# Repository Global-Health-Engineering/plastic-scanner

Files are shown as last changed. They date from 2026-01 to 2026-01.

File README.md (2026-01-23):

## Plastic Scanner
The goal of this project is to build a minimum viable product of the open-source [PlasticScanner](https://github.com/Plastic-Scanner) project and assess its suitability for the Global Health Engineering Lab. The design builds on the existing expertise of the project and incorporates the newest hardware version, Development Board 2.3. The overall objective of the project is to evaluate the scanner’s adaptability to the use case in Malawi and identify opportunities for improvement. This scanner is fully functional and can be reproduced for testing and development purposes. However, it is not recommended for any commercial application. Further development is still required.

<p align="center">
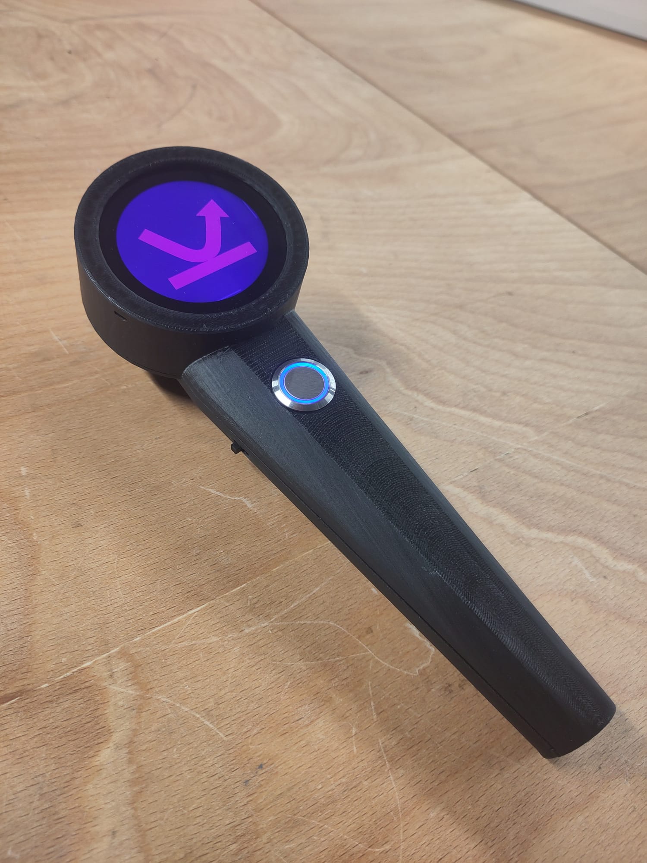
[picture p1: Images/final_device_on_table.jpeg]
  
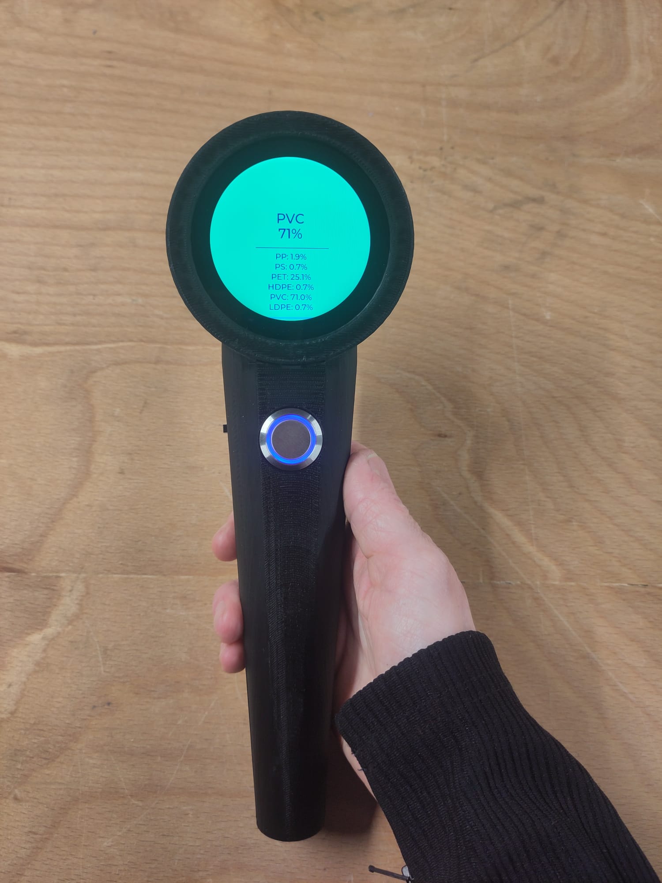
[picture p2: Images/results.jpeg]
  
</p>

## Introduction
Plastic is a widely used material, inexpensive to manufacture, and therefore a common choice for single-use products. However, due to its extensive use, global plastic pollution and its subsequent degradation in landfills into micro- and nanoplastics are threatening ecosystems (Walker & Fequet, 2023). Estimates indicate that plastic consumption will increase from 464 Mt/y in 2020 to over 700 Mt/y by 2050 (Dokl et al., 2024). Plastic recycling is established, but it first requires thorough separation of plastic components. Industrial plastic scanners employ various spectroscopic methods, with Near-Infrared (NIR) spectroscopy being the primary technology (Werner et al., 2023). Light is emitted, and the reflected relative light intensity from the material is measured to identify its composition.

Especially for small-scale recycling facilities and projects with limited financial resources, commercial plastic scanners are extremly expensive. Sorting is therefore done manually, which is often labor-intensive and inaccurate. An example is WASTE Adviser (WASTE Adviser Website, 2025), an NGO in Malawi that is establishing plastic beneficiation pathways for PET and HDPE. For the quality of the upcycled product, it is essential that the plastic is sorted with high accuracy. Otherwise, the recycled product suffers from embrittlement.

The PlasticScanner is an open source project which developed a low-cost plastic identification method. Utilizing inexpensive infrared LEDs and a machine learning model to identify the following six types of plastic:

plastic types

## How it works
The PlasticScanner allows the identification of six different plastic types using an approach called discrete near-infrared (NIR) spectroscopy. The IR LEDs on the Scanner module emit light one by one for a short period of time. Each time, the reflectance of the emitted light is measured by a photodiode.

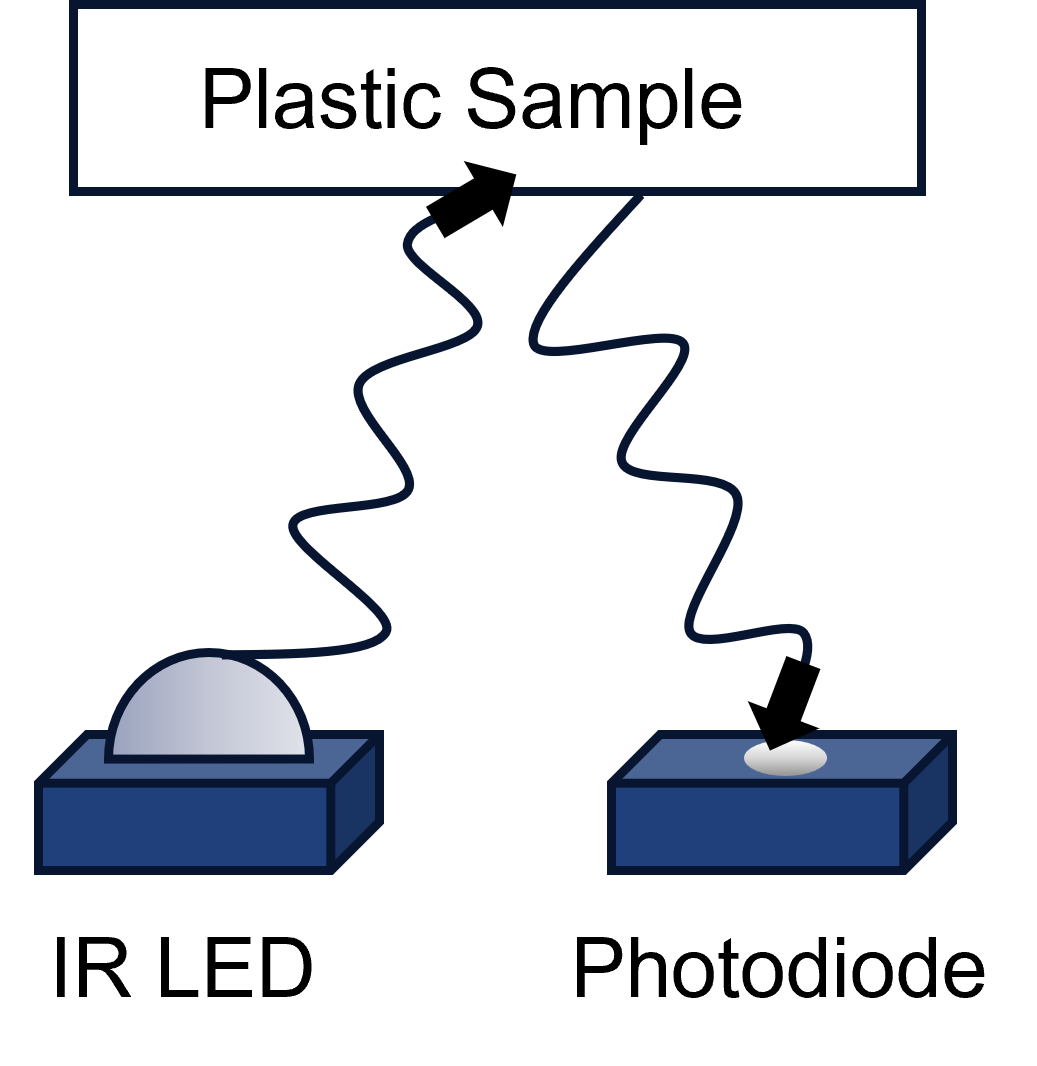
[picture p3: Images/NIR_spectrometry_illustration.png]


This results in a spectral analysis of the measured reflectance. Plastic identification is performed by comparing each measurement with the distinct reflectance spectra of the six plastic types (see illustration, for visualization only, not to scale). Since the device only provides eight readings at specific wavelengths and the actual reflectance spectra of plastics can be very similar, a machine learning model is applied. The model helps identify plastics more reliably without requiring a full spectral sweep. Additional information, such as color, can further improve the model, as dark plastics are particularly challenging to identify with this method.

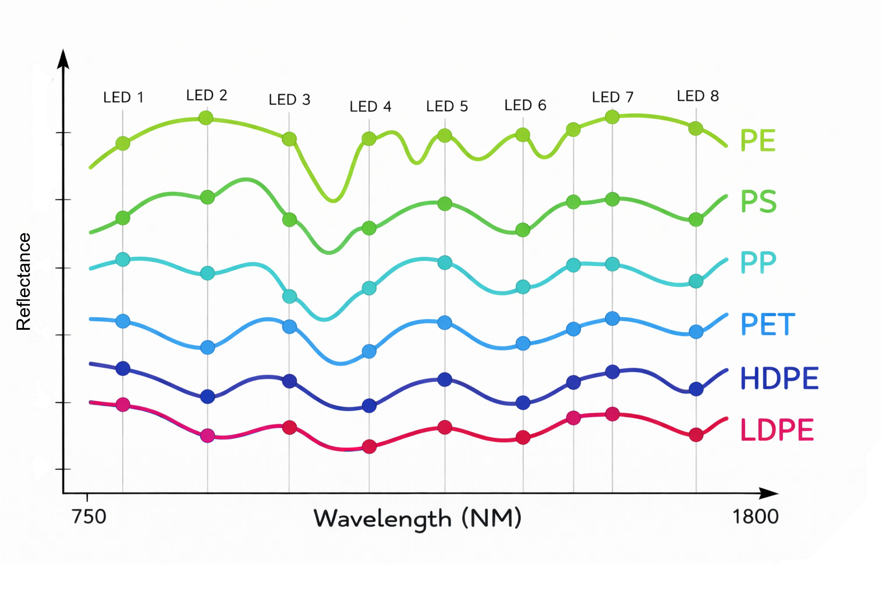
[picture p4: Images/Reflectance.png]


## Handheld Device
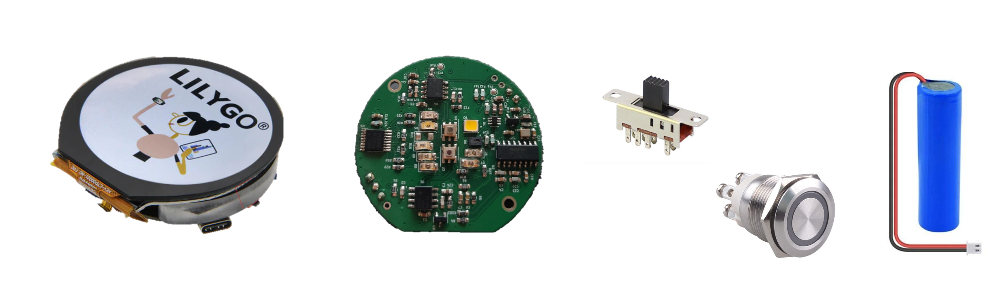
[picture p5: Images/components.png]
components


Components:
- 3D printed enclosure
- Scanning PCB (I²C for data transfer)
- Lilygo T-RGB UI interface, ESP32-S3 Microcontroller, USB-C port, Battery recharging, (I²C for data transfer)
- 3.7V 2600mAh Battery
- Button
- Power on/off shifter

## Future Work
- Create Training Data for machine learning Model with correct  IR LED range
- Retrain machine learning Model
- Add Color Sensor in Firmware
- Testing
- Supplychain addaptations (IR LED sourcing problems)

There is still a lot to improve! The most important point is that the current machine learning model still uses the old dataset, which relied on different IR LED ranges. To finalize this device, the model would need to be retrained with data for the wavelengths actually used (see Firmware). Due to this, testing has not yet been performed. Establishing the accuracy of the device and testing it for the intended use case is of high importance. The color sensor is included on the PCB but has not yet been implemented in the firmware. For future designs, the supplier of the IR LEDs should be changed, as especially high-wavelength LEDs are difficult to source and often have long delivery times. Switching to through-hole LEDs would increase the number of available suppliers and simplify sourcing.

## References
PlasticScanner Website: https://plasticscanner.com/ 

PlasticScanner Github: [Plastic-Scanner Project](https://github.com/Plastic-Scanner)

PCB: Lawrence R Kincheloe III, [handheld scanner](https://github.com/LokiMetaSmith/handheld-scanner.git)

CAD: Markus Glavind, [handheld scanner](https://github.com/Plastic-Scanner/handheld-scanner.git) 

Walker, T. R., & Fequet, L. (2023). Current trends of unsustainable plastic production and micro(nano)plastic pollution. TrAC Trends in Analytical Chemistry, 160, 116984. https://doi.org/10.1016/j.trac.2023.116984

Dokl, M., Copot, A., Krajnc, D., Fan, Y. V., Vujanović, A., Aviso, K. B., Tan, R. R., Kravanja, Z., & Čuček, L. (2024). Global projections of plastic use, end-of-life fate and potential changes in consumption, reduction, recycling and replacement with bioplastics to 2050. Sustainable Production and Consumption, 51, 498–518. https://doi.org/10.1016/j.spc.2024.09.025 

Werner, T., Taha, I., & Aschenbrenner, D. (2023). An overview of polymer identification techniques in recycling plants with focus on current and future challenges. Procedia CIRP, 120, 1381–1386. https://doi.org/10.1016/j.procir.2023.09.180

WASTE Adviser Website. (2025, Oktober 7). https://www.wasteadvisersmw.org/eu-building-better

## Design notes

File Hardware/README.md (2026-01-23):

## Hardware
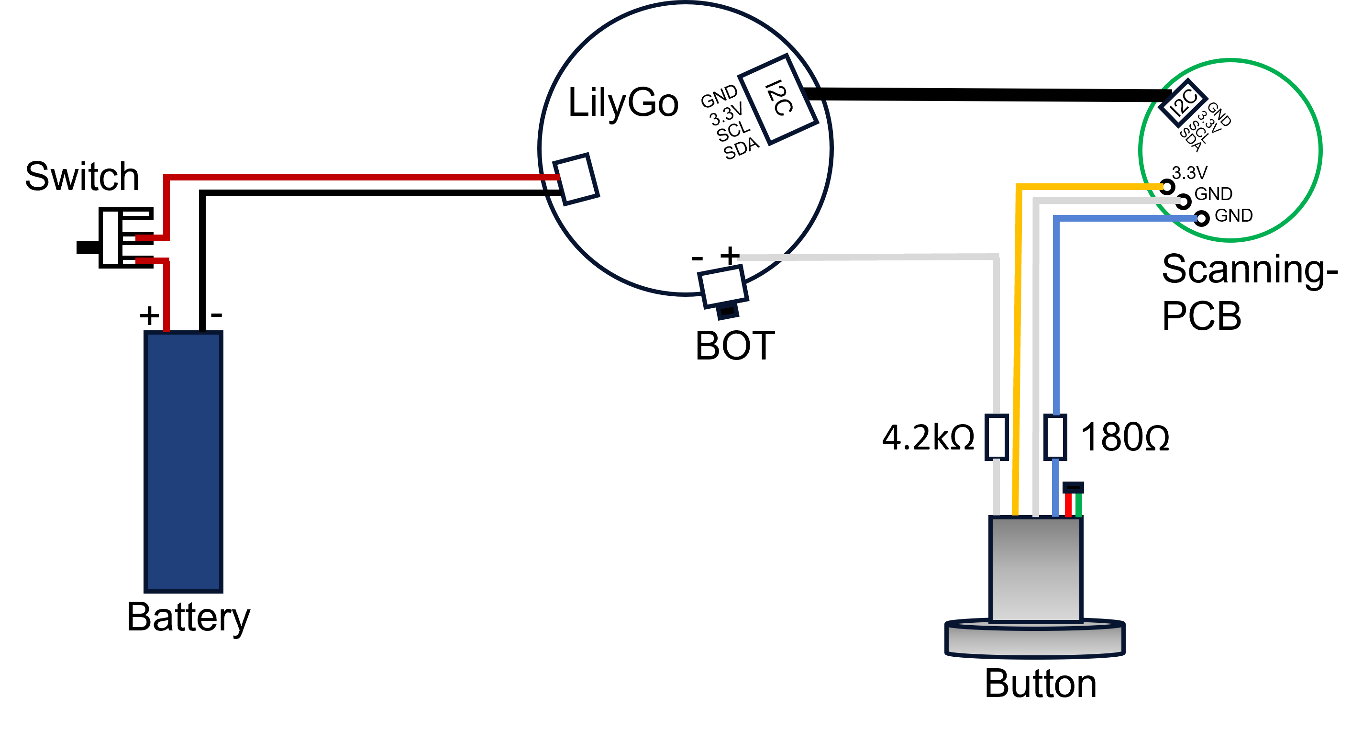
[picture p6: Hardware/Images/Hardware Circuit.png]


The hardware has the following components:

- Scanning PCB
- Lilygo T-RGB (ESP32-S3, Touch Screen, Battery recharging cycle, USB-C port, SD card)
- Button
- on/off Switch
- 3.7V 2600mAh Battery, rechargable 

Since the Lilygo board does not provide any dedicated external input pins, the onboard BOOT button was repurposed as an external input. Although the Scanning PCB includes additional external inputs, using them would require transmitting an extra button signal over the existing I²C link between the two boards, which would significantly increase implementation complexity.

## Scanning PCB
The scanning PCB was adapted from Lawrence Kincheloe's design, which represents the latest version of the handheld PlasticScanner. The IR LED wavelengths were modified to use available LEDs, and a few resistor values were adjusted accordingly.

Lawrence R Kincheloe III, [handheld scanner](https://github.com/LokiMetaSmith/handheld-scanner.git)

The PCB was soldered by hand using low-temperature solder paste, a soldering iron, a hot-air gun, and a microscope. The 1650nm IR LED is still missing, since its delivery data has been pushed to the 18.08.2026. 

<p align="center">
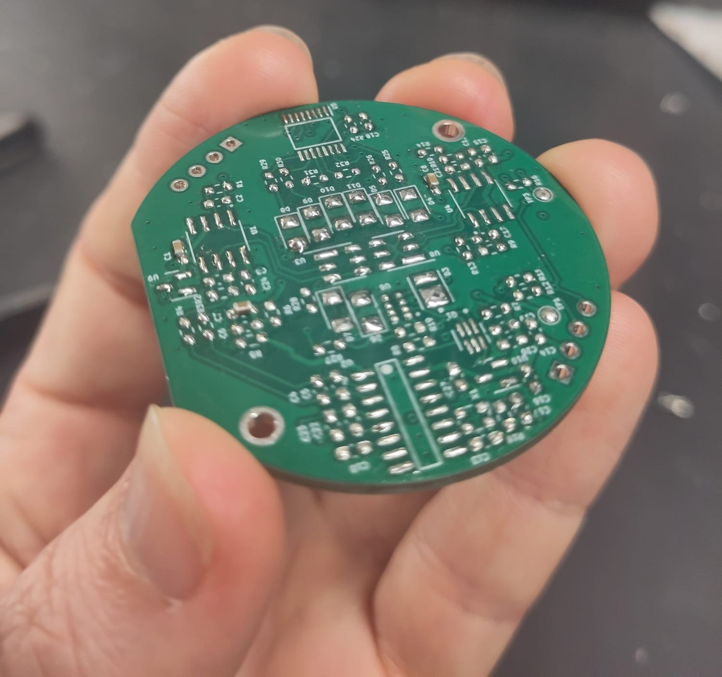
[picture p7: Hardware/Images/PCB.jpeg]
  
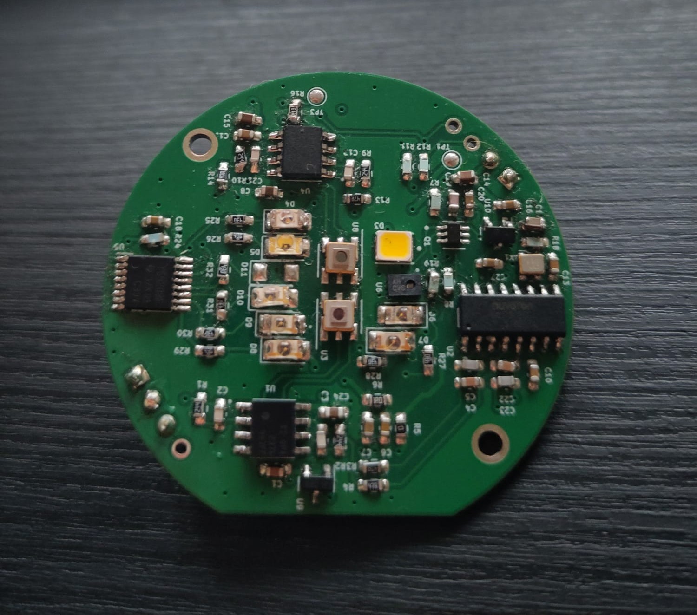
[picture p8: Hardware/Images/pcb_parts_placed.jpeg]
  
</p>

## Further Work
- IR LED sourcing problems -> change to push through LED's instead of SMD
- Separated LED PCB (first design exists)
- Find better solution for Button Signal (currently BOOT Button repurposed as an external input)
- to reduce cost the design could be changerd to only one photodiode or the LED count could be reduced

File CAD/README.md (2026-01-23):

## Design Enclosure 
The enclosure was designed to house the following components:
- Lilygo T-RGB board
- PCB scanner module
- Button
- 3.7V Battery (JST mini connector)
- On/Off switch
- 2x M3 screws (one 20mm, one 10mm)

The design includes a holding space for the battery and multiple fixtures for all other components. Since the project is still in the development phase, all fixtures were kept simple and reversible to ensure easy access to the components. Additionally, screw holders were added to provide the option of closing the device. These are intended for use with wooden screws and cannot be opened indefinitely, as the threads may break. However, the device closes firmly without screws, so for development purposes, they are not required.

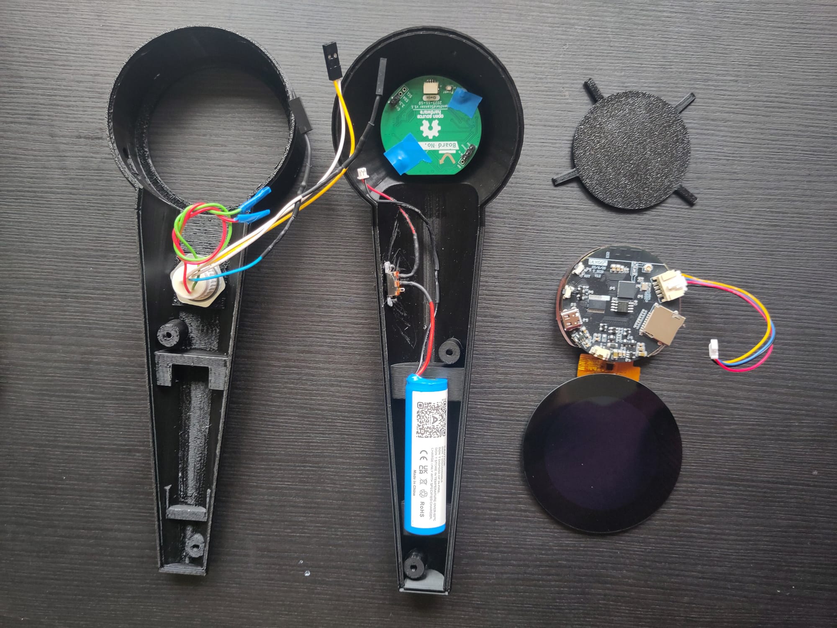
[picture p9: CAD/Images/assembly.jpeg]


## Printing Orientation:
A Bambu Studio printer was used with standard black PLA filament. The printing orientation was optimized for better surface texture. It was found to be best to orient the top part with the open side facing down, and the bottom part with the open side facing up. The open side is the side where the components are mounted. Printing at a slower speed with a layer height of 0.1 mm per slice produced the most uniform and pleasant-to-touch surface.

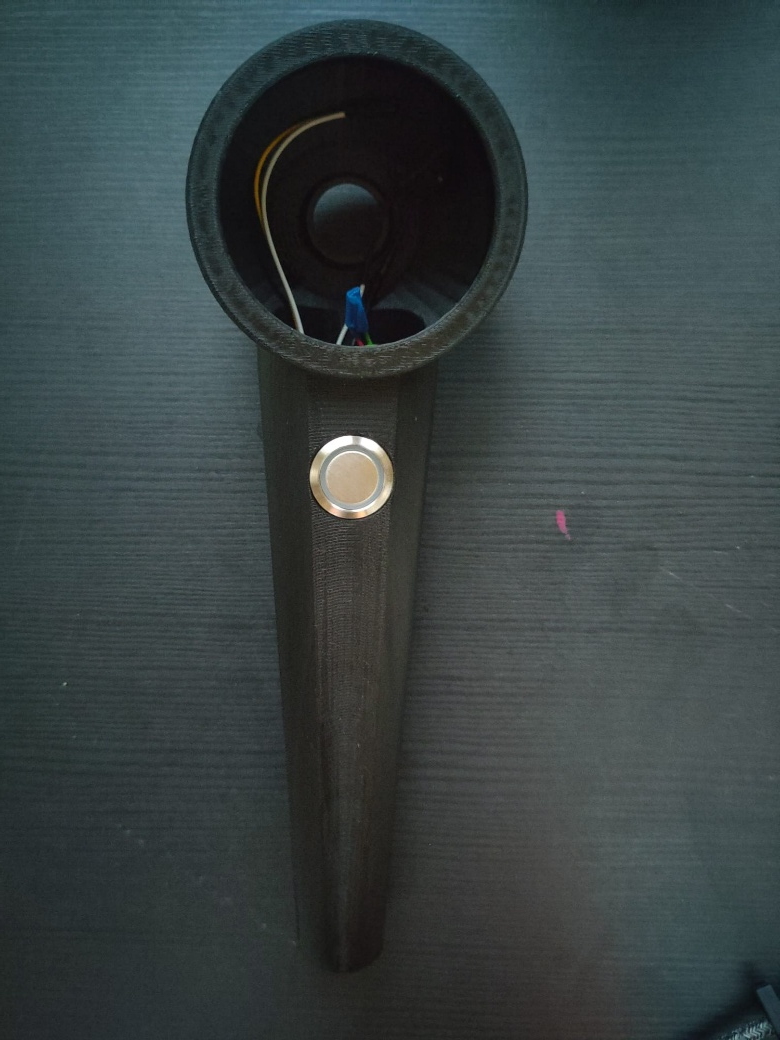
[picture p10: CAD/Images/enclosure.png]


## Further Work:
The USB-C port access could be improved and the fixtures changed to more durable solutions, for a final design. 

## References: 
The CAD was mainly influenced by the design analysis from Markus Glavind and Brandt Gregersen Gustav found here: 

Markus Glavind & Brandt Gregersen Gustav. (2023). PlasticScanner—Development and product realisation of a NIR polymer scanner. Master Thesis, DTU, 122.

Markus Glavind, [handheld scanner](https://github.com/Plastic-Scanner/handheld-scanner.git)

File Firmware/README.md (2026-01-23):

## Firmware
This is the firmware for the handheld PlasticScanner using a LilyGO board and is built as a PlatformIO project. The firmware can initiate a scan and send the received data to the machine learning model. The model then provides a prediction of which type of plastic was scanned. Since the current model was trained with different IR LEDs, the results are not accurate. The model would need to be retrained to generate correct predictions.

In the illustration, the 1720 nm LED is shown in red. It is currently unavailable and was replaced with a (green) 850 nm LED. The orange 1650 nm LED was initially available (delivery date pushed to 18.08.2026) but has now also been discontinued.

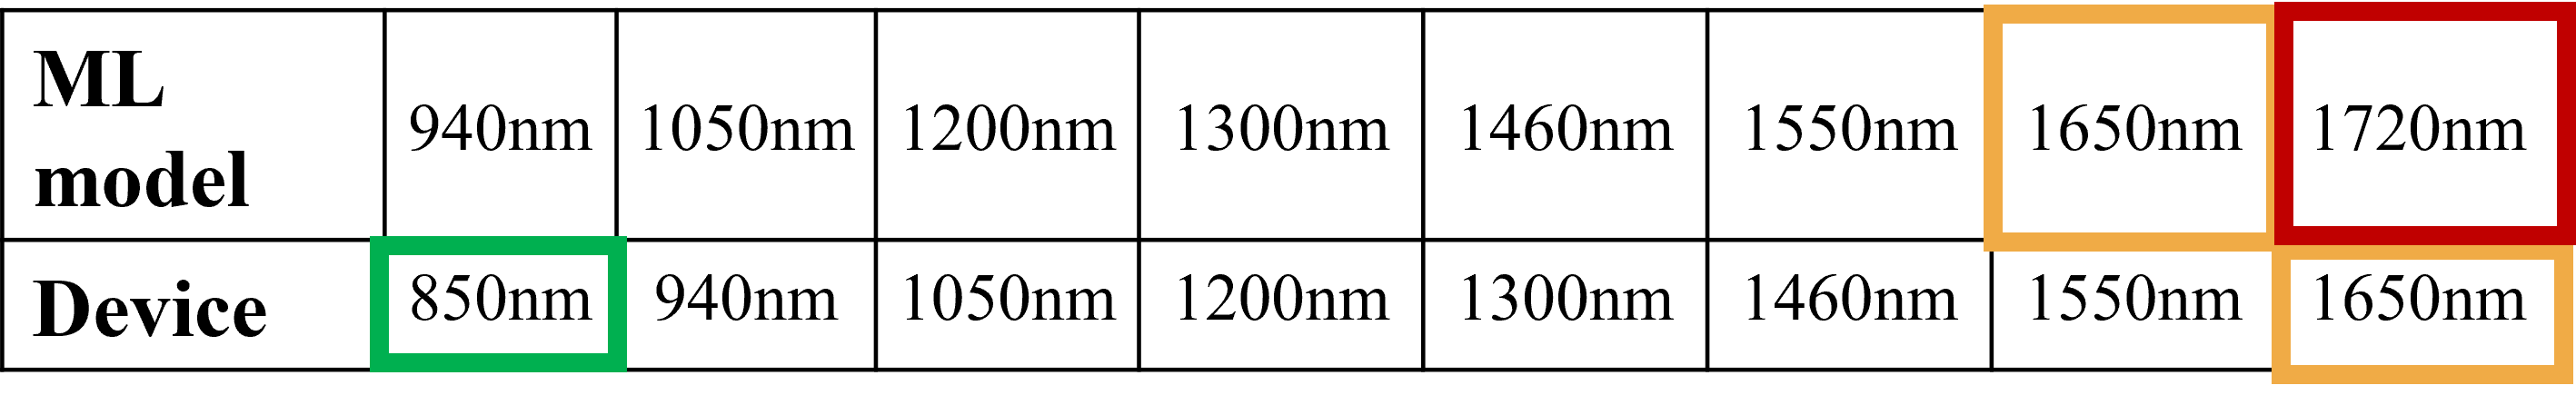
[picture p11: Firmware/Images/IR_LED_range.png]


Additionally, the firmware is still implemented as an example within the complete LilyGO firmware. This is necessary because the ESP32-S3 crashes immediately after startup if the firmware is used outside of the example structure. To run the current firmware, the platformio.ini file needs to be configured as follows:
 
<code style="color:red;">src_dir = examples/PlasticScanner</code>

Implemented features:
- Deep-sleep after long button press
- Deep-sleep after timeout of 5min
- Waking from Deep-sleep with long button press
- Scan after short button press
- old machine learning Model
- Startup UI
- Inital UI
- Scanning UI
- Results UI

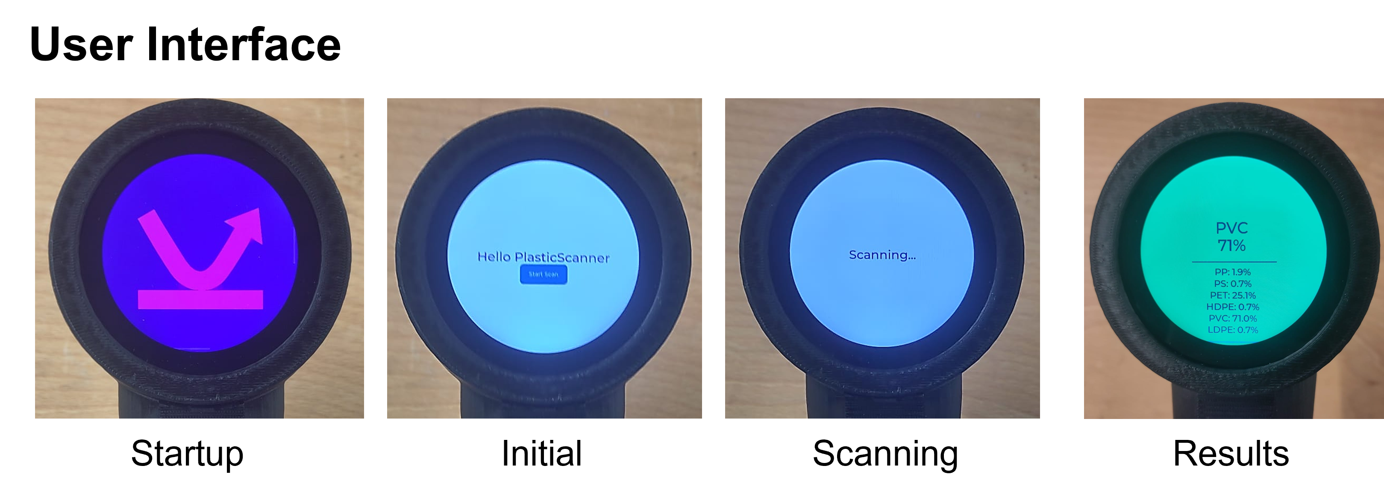
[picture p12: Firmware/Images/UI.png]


The firmware can be uploaded to the LilyGO by pressing the BOOT and RESET buttons simultaneously, then releasing RESET first, followed by BOOT, and immediately starting the firmware upload.

## Future Work
The next steps should be generating training data for the machine learning model, particularly for the 850 nm LED, and reviewing the available training data from the PlasticScanner project. Different versions of the model should be compared before retraining one of them with the specified IR LED wavelength range. Additionally, the AS7341 color sensor could be implemented in the firmware and incorporated into the training data.

## References
This firmware is based on the LilyGo T-RGB Firmware:
- https://github.com/Xinyuan-LilyGO/LilyGo-T-RGB.git

Machine Learning Repositories:
- https://github.com/Plastic-Scanner/Machine-Learning.git

Traning Data:
- https://github.com/Plastic-Scanner/Data.git 

Visualization, especially for Developement Board:
- https://github.com/Plastic-Scanner/PSplot.git

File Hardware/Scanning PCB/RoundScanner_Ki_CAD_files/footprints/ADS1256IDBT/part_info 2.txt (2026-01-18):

Manufacturer=Texas Instruments
PartNumber=ADS1256IDBT
PartCategory=Integrated Circuit
PackageCategory=Small Outline Packages
PinCount=28
Version=3.1
Released=2017-01-12 12:59:53
Downloaded=2022-05-06 10:48:30
3D=Y

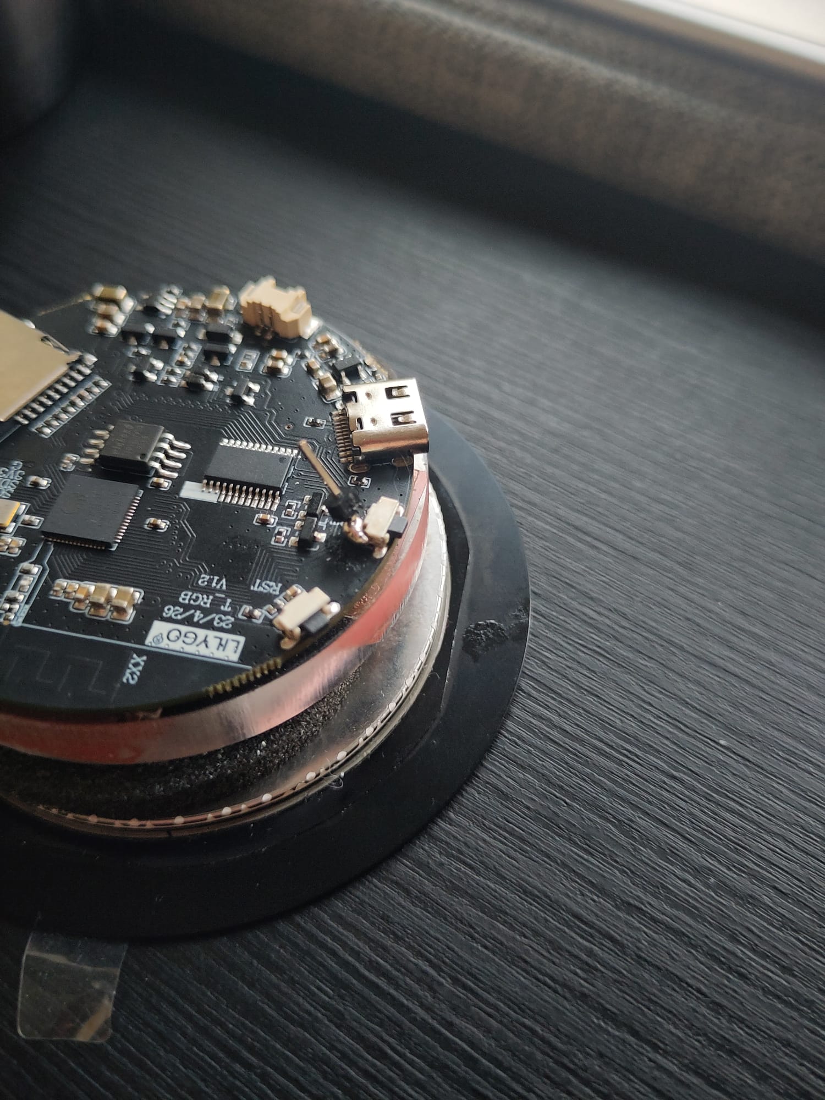
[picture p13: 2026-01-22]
Hardware/Images/highjacked_boot_pin.jpeg

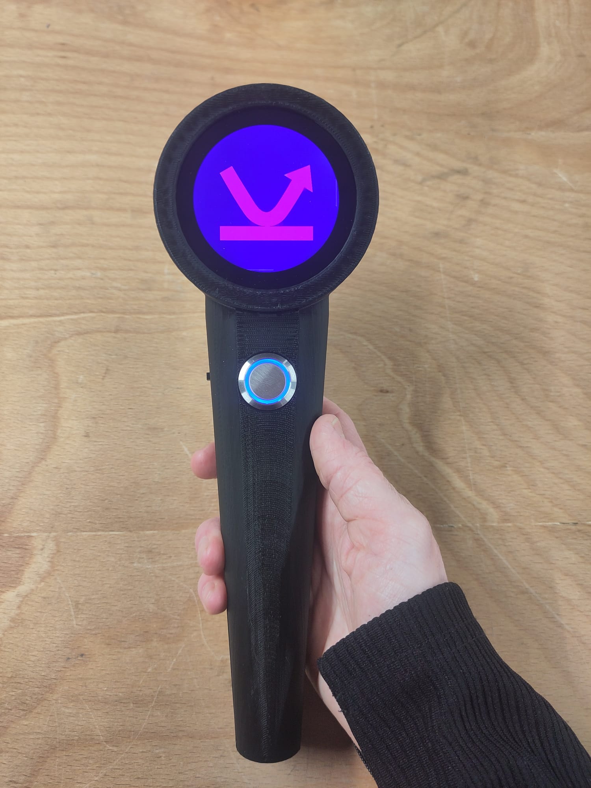
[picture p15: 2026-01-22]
Images/final_device.jpeg

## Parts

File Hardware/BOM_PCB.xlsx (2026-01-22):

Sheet: BOM Handheld
Part Number | sourced | placed | Designator | cathode/anode marking | Notes/Name | Footprint | Quantity | Manufacturer | Manufacturer Part Number (MPN) | Vendor / Supplier | Vendor P/N | Stock | Available | Unit Cost (USD) | Cost per device
1 | y | y | PCB Assembly |  | scanner board loki |  | 1 | JLCPCB |  |  |  | 5 | 4.00 | 1.36 | 1.36
2 | y | y | C1, C7, C10, C11, C13, C16, C20, C27 |  | 0.1uF 25V | C_0603_1608Metric_Pad1.08x0.95mm_HandSolder | 8 | KEMET | C0603C104K3RACTU | Digikey | 399-C0603C104K3RACTUDKR-ND | 16 | 8.00 | 0.08 | 0.64
3 | y | y | C2, C3, C12, C21 |  | 51pF 50V | C_0603_1608Metric_Pad1.08x0.95mm_HandSolder | 4 | KEMET | C0603X510K3HACTU | Digikey | 399-C0603X510K3HACTUDKR-ND | 8 | 4.00 | 0.1 | 0.4
4 | y | y | C14, C15, C19 |  | 10uF 10V | C_0603_1608Metric_Pad1.08x0.95mm_HandSolder | 3 | Murata Electronics | GRM188Z71A106KA73D | Digikey | 490-GRM188Z71A106KA73DDKR-ND | 6 | 3.00 | 0.28 | 0.84
5 | y | y | C4, C22 |  | 47nF 50V | C_0603_1608Metric_Pad1.08x0.95mm_HandSolder | 2 | KEMET | C0603X473J4RECAUTO | Digikey | 399-C0603X473J4RECAUTODKR-ND | 4 | 2.00 | 0.21 | 0.42
6 | y | y | C5, C23 |  | 100pF 50V | C_0603_1608Metric_Pad1.08x0.95mm_HandSolder | 2 | KEMET | C0603C101M3RACAUTO | Digikey | 399-C0603C101M3RACAUTODKR-ND | 4 | 2.00 | 0.24 | 0.48
7 | y | y | C6, C8, C24 |  | 1uF 25V | C_0603_1608Metric_Pad1.08x0.95mm_HandSolder | 1 | Taiyo Yuden | TMK107B7105KA-T | Digikey | 587-2984-6-ND | 4 | 3.00 | 0.08 | 0.08
8 | y | y | C17 |  | 22uF 25V | C_0603_1608Metric_Pad1.08x0.95mm_HandSolder | 1 | Murata Electronics | GRM188C61E226ME01W | Digikey | 490-GRM188C61E226ME01WDKR-ND | 4 | 3.00 | 0.41 | 0.41
9 | y | y | R7, R8, R11, R12, R19 |  | 10k | R_0603_1608Metric_Pad0.98x0.95mm_HandSolder | 5 | Vishay | MCT06030C1002FP500 | Digikey | MCT0603-10.0K-CFDKR-ND | 10 | 5.00 | 0.1 | 0.5
10 | y | y | R1, R2, R9, R10 |  | 240k | R_0603_1608Metric_Pad0.98x0.95mm_HandSolder | 4 | YAGEO | RT0603FRE07240KL | Digikey | 13-RT0603FRE07240KLDKR-ND | 8 | 4.00 | 0.1 | 0.4
11 | y | y | R3, R4, R13, R14 |  | 301 | R_0603_1608Metric_Pad0.98x0.95mm_HandSolder | 4 | YAGEO | RT0603FRE07301RL | Digikey | 13-RT0603FRE07301RLDKR-ND | 8 | 4.00 | 0.1 | 0.4
12 | y | y | R16, R26, R29, R30 |  | 150 | R_0603_1608Metric_Pad0.98x0.95mm_HandSolder | 4 | Vishay | MCT06030C1500FP500 | Digikey | MCT0603-150-CFDKR-ND | 8 | 4.00 | 0.1 | 0.4
13 | y | y | R18, R16 |  | 1k, R16 = 100 Ohm | R_0603_1608Metric_Pad0.98x0.95mm_HandSolder | 2 | Vishay | MCT06030C1001FP500 | Digikey | MCT0603-1.00K-CFDKR-ND | 4 | 2.00 | 0.1 | 0.2
14 | y | y | R27, R28 |  | 240 | R_0603_1608Metric_Pad0.98x0.95mm_HandSolder | 2 | Vishay | MCT06030C2400FP500 | Digikey | 749-1760-6-ND | 4 | 2.00 | 0.1 | 0.2
15 | y | y | R25 |  | 56 | R_0603_1608Metric_Pad0.98x0.95mm_HandSolder | 1 | YAGEO | RT0603FRE0756RL | Digikey | 13-RT0603FRE0756RLDKR-ND | 4 | 3.00 | 0.1 | 0.1
16 | y | y | R31 |  | 40 | R_0603_1608Metric_Pad0.98x0.95mm_HandSolder | 1 | Stackpole Electronics Inc | RMCF0603FT40R2 | Digikey | RMCF0603FT40R2DKR-ND | 4 | 3.00 | 0.1 | 0.1
17 | y | y | R32 |  | 130 | R_0603_1608Metric_Pad0.98x0.95mm_HandSolder | 1 | YAGEO | RT0603FRE07130RL | Digikey | 13-RT0603FRE07130RLDKR-ND | 4 | 3.00 | 0.1 | 0.1
18 | y | y | D2 |  | POWER LED RED | LED_0805_2012Metric_Pad1.15x1.40mm_HandSolder | 1 | Visual Communications Company - VCC | LSM0805412V | Digikey | 28-LSM0805412VDKR-ND | 3 | 2.00 | 0.43 | 0.43
19 | y | y | D3 | T | EAHC2835WD6 | Everlight-EAHC2835WD6-MFG | 1 | Everlight Electronics Co Ltd | EAHC2835WD6 | Digikey | 1080-1461-6-ND | 2 | 1.00 | 0.29 | 0.29
20 | y | y | D4 | T | 850bm DOM | LED_1206_3216Metric_Pad1.42x1.75mm_HandSolder | 1 | Würth Elektronik | 15412085A3060 | Digikey | 732-12009-6-ND | 2 | 1.00 | 0.57 | 0.57
21 | y | y | D5 | cathode dot | 940nm DOM | LED_1206_3216Metric_Pad1.42x1.75mm_HandSolder | 1 | SunLED | XZTNI55W-3 | Digikey | 1497-1368-6-ND | 2 | 1.00 | 0.48 | 0.48
22 | y | y | D6 | cathode dot | 1050nm DOM | LED_1206_3216Metric_Pad1.42x1.75mm_HandSolder | 1 | Marktech Optoelectronics | MTSM5010-843-IR | Digikey | 1125-1359-ND | 2 | 1.00 | 12.49 | 12.49
23 | y | y | D7 | anode dot | 1200nm DOM | LED_1206_3216Metric_Pad1.42x1.75mm_HandSolder | 1 | Marktech Optoelectronics | MTSM0012-844-IR | Digikey | 1125-MTSM0012-844-IRDKR-ND | 2 | 1.00 | 13.1 | 13.1
24 | y | y | D8 | anode dot | 1300nm DOM | LED_1206_3216Metric_Pad1.42x1.75mm_HandSolder | 1 | Marktech Optoelectronics | MTSM0013-844-IR | Digikey | 1125-MTSM0013-844-IRDKR-ND | 2 | 1.00 | 13.1 | 13.1
25 | y | y | D9 | anode dot | 1460nm DOM | LED_1206_3216Metric_Pad1.42x1.75mm_HandSolder | 1 | Marktech Optoelectronics | MTSM6014-844-IR | Digikey | 1125-MTSM6014-844-IRDKR-ND | 2 | 1.00 | 13.1 | 13.1
26 | y | y | D10 | anode dot | 1550nm DOM not available | LED_1206_3216Metric_Pad1.42x1.75mm_HandSolder | 1 | Marktech Optoelectronics | MTSM5015-194-IR | Digikey | 1125-MTSM5015-194-IRDKR-ND | 2 | 1.00 | 13.1 | 13.1
27 | y | y | D11 | cathode dot | 1650nm DOM not available | LED_1206_3216Metric_Pad1.42x1.75mm_HandSolder | 1 | Marktech Optoelectronics | MTSM5016-843-IR or MTSM5016-199-IR | Digikey | 1125-1362-ND | 0 | -1.00 | 23.9 | 0
28 | y | y | U1, U4 |  | OPA2376AID | SOIC127P599X175-8N | 2 | Texas Instruments | OPA2376AID | Digikey | 296-26263-5-ND | 3 | 1.00 | 3.15 | 6.3
29 | y | y | U2 |  | NAU7802SGI | Nuvoton-NAU7802SGI | 1 | Nuvoto Technology Corporation | NAU7802SGI | Digikey | NAU7802SGI-ND | 3 | 2.00 | 1.62 | 1.62
30 | y | y | U3 |  | MTSM2601SMF1-100 | SENSOR PHOTODIODE 800-2600NM SMD | 1 | Marktech Optoelectronics | MTSM2601SMF1-100 | Digikey | 1125-MTSM2601SMF1-100-ND | 1 | 0.00 | 36.62 | 36.62
31 | y | y | U5 |  | TLC59208FIPWR | SOP65P640X120-16N | 1 | Texas Instruments | TLC59208FIPWR | Digikey | 296-36508-6-ND | 3 | 2.00 | 1.97 | 1.97
32 | y | y | U6 |  | AS7341-DLGT color sensor | PSON80P310X200X110-8N | 1 | ams-OSRAM USA INC. | AS7341-DLGT | Digikey | AS7341-DLGTDKR-ND | 2 | 1.00 | 7.64 | 7.64
33 | y | y | U7 |  | AP7312-1833W6-7 | AP7312-1833W6-7 | 1 | Diodes Incorporated | AP7312-1833W6-7 | Digikey | AP7312-1833W6-7DIDKR-ND | 2 | 1.00 | 0.53 | 0.53
34 | y | y | U8 |  | MTSM1346SMF1-100 | SENSOR PHOTODIODE 1300NM 6SMD | 1 | Marktech Optoelectronics | MTSM1346SMF1-100 | Digikey | 1125-MTSM1346SMF1-100-ND | 1 | 0.00 | 33.55 | 33.55
35 | y | y | U9 |  | AP2120N-2.5TRG1 | IC REG LINEAR 2.5V 150MA SOT23 | 1 | Diodes Incorporated | AP2120N-2.5TRG1 | Digikey | AP2120N-2.5TRG1DICT-ND | 3 | 2.00 | 0.14 | 0.14
36 | y | y | U10 |  | AP2125N-1.8TRG1 | IC REG LINEAR 1.8V 300MA SOT23-3 | 1 | Diodes Incorporated | AP2125N-1.8TRG1 | Digikey | AP2125N-1.8TRG1DICT-ND | 3 | 2.00 | 0.17 | 0.17
37 | y | y | X1 |  | 4.9152 MHz | Oscillator_SMD_ECS_2520MV-xxx-xx-4Pin_2.5x2.0mm | 1 | ECS Inc. | ECS-2520MVLC-049-BN-TR | Digikey | 50-ECS-2520MVLC-049-BN-DKR-ND | 3 | 2.00 | 1.24 | 1.24
38 | y | y | Q1 |  | BSS138DW-7-F | Diodes_Inc._-_BSS138DW-7-F-A | 1 | Diodes Incorporated | BSS138DW-7-F | Digikey | BSS138DW-FDIDKR-ND | 2 | 1.00 | 0.45 | 0.45
39 | y | y | J1 |  | ThroughHole Pin socket | PinSocket_1x04_P2.54mm_Vertical | 1 |  |  |  |  | 5 | 4.00 | 0 | 0
40 | y | y | J3 |  | I2C JST socket | JST_SH_SM04B-SRSS-TB_1x04-1MP_P1.00mm_Horizontal | 1 | JST Sales America Inc. | SM04B-SRSS-TB | Digikey | 455-SM04B-SRSS-TBDKR-ND | 5 | 4.00 | 0.5 | 0.5
41 | y | y | J4 |  | ThroughHole Pin socket | PinSocket_1x04_P2.54mm_Vertical | 1 |  |  |  |  | 5 | 4.00 | 0 | 0
42 | y | y |  | Assembly component | Button |  | 1 | Lumex Opto/Components Inc. | WS48M-A12RGB12 | Digikey | 67-WS48M-A12RGB12-ND | 1 | 1.00 | 18.3 | 18.3 | Total PCB $ | 164.42
43 | y | y |  | Assembly component | On/off switch |  | 1 | C&K | OS102011MS2QN1 | Digikey | CKN9565-ND | 1 | 1.00 | 0.71 | 0.71 | Total PCB Fr | 131.39
44 | y | y |  | Assembly component | LilyGo-TRGB |  | 1 | LilyGo | Lilygo T-RGB ESP32-S3 2.1/2.8 round display | Lilygo |  | 1 | 1.00 | 30.04 | 30.04
45 | y | y |  | Assembly component | 3.7V Battery |  | 1 | Nvidia | AccuCell Akku Nvidia Shield P2570, Nvidia LC18650 | Digitec | 23192203 | 1 | 1.00 | 38.03 | 38.03
46 | y | y |  | Assembly component | I2C JST Cable, QWIIC CABLE GROVE ADAPTER 100MM |  | 1 | SparkFun Electronics | 15109 | Digikey | 1568-15109-ND | 1 | 1.00 | 1.95 | 1.95
 |  |  |  |  |  |  |  |  |  |  |  |  |  | Total $ | 253.45
 |  |  |  |  |  |  |  |  |  |  |  |  |  | Total Fr | 202.53

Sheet: BOM Developement board
Part Number | sourced | Designator | Part Name / Description | Notes | Manufacturer | Manufacturer Part Number (MPN) | Vendor / Supplier | Vendor P/N | Quantity per Assembly | Footprint | Procurement Type | Stock | Available | Material / Specification | Unit Cost (USD) | Total Cost (USD)
1 | y | board | Development board |  | JLCPCB |  |  |  | 1 | - | Buy | 5 | 4
2 | y | C1, C7, C10, C11, C14, C16 | Capacitor 0.1u 10V |  |  |  |  |  | 6 | C_0805_2012Metric_Pad1.18x1.45mm_HandSolder | Lab stock | 12 | 6 | 0.1u
3 | y | C2, C3 | Capacitor 51p 50V |  |  |  |  |  | 2 | C_0805_2012Metric_Pad1.18x1.45mm_HandSolder | Lab stock | 4 | 2 | 51p
4 | y | C5, C8 | Capacitor 100p 50V |  |  |  |  |  | 2 | C_0805_2012Metric_Pad1.18x1.45mm_HandSolder | Lab stock | 4 | 2 | 100p
5 | y | C6, C15 | Capacitor 22u 16V |  |  |  |  |  | 2 | C_0805_2012Metric_Pad1.18x1.45mm_HandSolder | Lab stock | 4 | 2 | 22u
6 | y | C4 | Capacitor 47n 50V |  |  |  |  |  | 1 | C_0805_2012Metric_Pad1.18x1.45mm_HandSolder | Lab stock | 4 | 3 | 47n
7 | y | C9 | Capacitor 330p 16V |  |  |  |  |  | 1 | C_0805_2012Metric_Pad1.18x1.45mm_HandSolder | Lab stock | 4 | 3 | 330p
8 | y | C13 | Capacitor 10u 16V |  |  |  |  |  | 1 | C_0805_2012Metric_Pad1.18x1.45mm_HandSolder | Lab stock | 4 | 3 | 10u
9 | y | R15, R16, R17, R18, R19, R20, R21, R22 | Resistor 47 |  |  |  |  |  | 8 | R_0805_2012Metric_Pad1.20x1.40mm_HandSolder | Lab stock | 16 | 8 | 47
10 | y | R7, R8, R11 | Resistor 100 | change dependent on what LED ordered R8 = 75, R11 = 12, R7 = 91 or 100 |  |  |  |  | 3 | R_0805_2012Metric_Pad1.20x1.40mm_HandSolder | Lab stock | 6 | 3 | 100
11 | y | R1, R2 | Resistor 240k |  |  |  |  |  | 2 | R_0805_2012Metric_Pad1.20x1.40mm_HandSolder | Lab stock | 4 | 2 | 240k
12 | y | R3,R4 | Resistor 300 |  |  |  |  |  | 2 | R_0805_2012Metric_Pad1.20x1.40mm_HandSolder | Lab stock | 4 | 2 | 300
13 | y | R5, R6 | Resistor 51 |  |  |  |  |  | 2 | R_0805_2012Metric_Pad1.20x1.40mm_HandSolder | Lab stock | 4 | 2 | 51
14 | y | R9, R10 | Resistor 10k |  |  |  |  |  | 2 | R_0805_2012Metric_Pad1.20x1.40mm_HandSolder | Lab stock | 4 | 2 | 10k
15 | y | R14 | Resistor 1k |  |  |  |  |  | 1 | R_0805_2012Metric_Pad1.20x1.40mm_HandSolder | Lab stock | 4 | 3 | 1k
16 | y | D3, D12 | LED Red 0805 2012 metric | soldering max 260°C | Visual Communications Company - VCC | LSM0805412V | Digikey | 28-LSM0805412VDKR-ND | 2 | LED_0805_2012Metric_Pad1.15x1.40mm_HandSolder | Buy | 4 | 2 | red
17 | y | D1 | Sensor for Photodiodes | soldering max 260°C | Advanced Photonix | 0090-3111-185 | Digikey | 209-0090-3111-185DKR-ND | 1 | D_1206_3216Metric_Pad1.42x1.75mm_HandSolder | Buy | 4 | 3 | 800nm-1700nm, 0.95 A/W @ 1300nm, 1.0 A/W @ 1500nm
18 | y | D2 | LED Blue 0805 2012 metric | soldering max 260°C | Visual Communications Company - VCC | LSM0805463V | Digikey | 28-LSM0805463VDKR-ND | 1 | LED_0805_2012Metric_Pad1.15x1.40mm_HandSolder | Buy | 3 | 2 | blue
19 | y | D4 | IR 850nm | soldering max 260°C | Würth Elektronik | 15412085A3060 | Digikey | 732-12009-6-ND | 1 | LED_1206_3216Metric_Pad1.42x1.75mm_HandSolder | Buy | 2 | 1 | 855nm
20 | y | D5 | IR 940nm DOM | soldering max 260°C | SunLED | XZTNI55W-3 | Digikey | 1497-1368-6-ND | 1 | LED_1206_3216Metric_Pad1.42x1.75mm_HandSolder | Buy | 2 | 1 | 940nm
21 | y | D6 | IR 1050nm DOM | soldering max 260°C | Marktech Optoelectronics | MTSM5010-843-IR | Digikey | 1125-1359-ND | 1 | LED_1206_3216Metric_Pad1.42x1.75mm_HandSolder | Buy | 2 | 1 | 1050nm
22 | y | D7 | IR 1200nm DOM | soldering max 260°C | Marktech Optoelectronics | MTSM0012-844-IR | Digikey | 1125-MTSM0012-844-IRDKR-ND | 1 | LED_1206_3216Metric_Pad1.42x1.75mm_HandSolder | Buy | 2 | 1 | 1200nm
23 | y | D8 | IR 1300nm DOM | soldering max 260°C | Marktech Optoelectronics | MTSM0013-844-IR | Digikey | 1125-MTSM0013-844-IRDKR-ND | 1 | LED_1206_3216Metric_Pad1.42x1.75mm_HandSolder | Buy | 2 | 1 | 1300nm
24 | y | D9 | IR 1460nm DOM | soldering max 260°C | Marktech Optoelectronics | MTSM6014-844-IR | Digikey | 1125-MTSM6014-844-IRDKR-ND | 1 | LED_1206_3216Metric_Pad1.42x1.75mm_HandSolder | Buy | 2 | 1 | 1460nm
25 | y | D10 | IR 1550nm | DOM not available | Marktech Optoelectronics | MTSM5015-844-IR or MTSM5015-194-IR | Digikey | 1125-MTSM5015-844-IRDKR-ND | 1 | LED_1206_3216Metric_Pad1.42x1.75mm_HandSolder | Buy | 2 | 1 | 1550nm
26 | y | D11 | IR 1650nm | DOM not available | Marktech Optoelectronics | MTSM5016-843-IR or MTSM5016-199-IR | Digikey | 1125-1362-ND | 1 | LED_1206_3216Metric_Pad1.42x1.75mm_HandSolder | Buy | 0 | -1 | 1650nm
28 | y | U1 | low-noise operational amplifiers | amplifier AC/DC | Texas Instruments | OPA2376AID | Digikey | 296-26263-5-ND | 1 | SOIC127P599X175-8N | Buy | 3 | 2 | Amplifier AC-DC | 3.15
29 | y | U2 | 24bit analog digital converter | soldering max 260°C | Nuvoto Technology Corporation | NAU7802SGI | Digikey | NAU7802SGI-ND | 1 | Nuvoton-NAU7802SGI-0-0-0 | Buy | 3 | 2 |  | 1.62
30 | y | U3 | PMIC Voltageregulator 3.3V | soldering max 260°C | UMW | AMS1117-3.3 | Digikey | 4518-AMS1117-3.3DKR-ND | 1 | SOT-223-3_TabPin2 | Buy | 3 | 2 |  | 0.27
31 | y | U4 | LED driver IC linear PWM | soldering max 260°C, 50MA | Texas Instruments | TLC59208FIPWR | Digikey | 296-36508-6-ND | 1 | Texas_Instruments-TLC59208FIPWR-Level_A | Buy | 3 | 2 | 50mA
32 | y | SW1 | MCU Reset, push button |  | C&K | D6R90 F2 LFS | Digikey | 401-1995-ND | 1 | SW_PUSH_6mm | Buy | 2 | 1
33 | y | SW2 | Trigger, push button |  | C&K | D6R90 F2 LFS | Digikey | 401-1995-ND | 1 | SW_PUSH_6mm | Buy | 2 | 1
34 | y | A1 | Arduino Uno R3 | lab | Arduino | Arduino_UNO_R3 |  |  | 1 |  | Lab stock | 1 | 0
35 | y | FB1 | FerriteBead |  |  |  | Digikey |  | 1 |  | Buy | 4 | 3
36 | y | J1, J4, J5 | Conn_01x04 | P2.54mm vertical Socket | Adam Tech | SMC-1-04-1-GT | Digikey | 2057-SMC-1-04-1-GT-ND | 3 |  | Lab stock | 5 | 2
37 | y | J2 | Conn_01x08 | P2.54mm vertical Header | Samtec Inc. | TS-108-T-A-1 | Digikey | TS-108-T-A-1-ND | 1 |  | Lab stock | 5 | 4
38 | y | J3 | Qwiic, Connector |  | JST Sales America Inc. | SM04B-SRSS-TB | Digikey | 455-SM04B-SRSS-TBDKR-ND | 1 | JST_SH_SM04B-SRSS-TB_1x04-1MP_P1.00mm_Horizontal | Buy | 4 | 3

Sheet: BOM Jewiss
ID | Name | Designator | Footprint | Quantity | Manufacturer Part | Manufacturer | Supplier | Supplier Part | Stock | Available | Price
1 | board jewiss |  |  | 1 |  |  |  |  | 5 | 4
2 | LP5951MFX-1.5/NOPB | U5 | SOT-23-5_L2.9-W1.6-P0.95-LS2.8-BR | 1 | LP5951MFX-1.5/NOPB | TI(德州仪器) | LCSC | C2877802 | 3 | 2 | 1.154
3 | 0.1u | C12,C3,C9,C11 | L0603 | 4 | CL05A105KA5NQNC | SAMSUNG | LCSC | C52923 | 0 | -4 | 0.004
4 | 51p | C1,C2 | L0603 | 2 | CL05A105KA5NQNC | SAMSUNG | LCSC | C52923 | 0 | -2 | 0.004
5 | 47n | C4 | L0603 | 1 | CL05A105KA5NQNC | SAMSUNG | LCSC | C52923 | 0 | -1 | 0.004
6 | 100p | C5,C8 | L0603 | 2 | CL05A105KA5NQNC | SAMSUNG | LCSC | C52923 | 0 | -2 | 0.004
7 | 330p | C6,C7 | L0603 | 2 | CL05A105KA5NQNC | SAMSUNG | LCSC | C52923 | 0 | -2 | 0.004
8 | 22u | C10 | L0603 | 1 | CL05A105KA5NQNC | SAMSUNG | LCSC | C52923 | 0 | -1 | 0.004
9 | 240K | R1,R2,J1,J2,J3 | L0603 | 5 | RCT0212KJLF | HKR | LCSC | C174266 | 0 | -5
10 | 300 | R3,R4 | L0603 | 2 | RCT0212KJLF | HKR | LCSC | C174266 | 0 | -2
11 | 51 | R5,R6 | L0603 | 2 | RCT0212KJLF | HKR | LCSC | C174266 | 0 | -2
12 | SD0050-3111-011 | D1 | TO-46-2_BD5.5-P1.27-L | 1 | 1N4007W | BLUE ROCKET | LCSC | C328592 | 2 | 1 | 0.005
13 | HDR-M-2.54_1x8 | J4 | HDR-M-2.54_1X8 | 1 |  |  | LCSC | C190820 | 0 | -1 | 0.049
14 | 970nm | LED1 | LED1206-RD | 1 | 19-217/R6C-AL1M2VY/3T | EVERLIGHT(台湾亿光) | LCSC | C72044 | 0 | -1 | 0.019
15 | 1050nm | LED2 | LED1206-RD | 1 | 19-217/R6C-AL1M2VY/3T | EVERLIGHT(台湾亿光) | LCSC | C72044 | 2 | 1 | 0.019
16 | 1200nm | LED3 | LED1206-RD | 1 | 19-217/R6C-AL1M2VY/3T | EVERLIGHT(台湾亿光) | LCSC | C72044 | 0 | -1 | 0.019
17 | 1300nm | LED4 | LED1206-RD | 1 | 19-217/R6C-AL1M2VY/3T | EVERLIGHT(台湾亿光) | LCSC | C72044 | 2 | 1 | 0.019
18 | 1450nm | LED5 | LED1206-RD | 1 | 19-217/R6C-AL1M2VY/3T | EVERLIGHT(台湾亿光) | LCSC | C72044 | 0 | -1 | 0.019
19 | 1500nm | LED6 | LED1206-RD | 1 | 19-217/R6C-AL1M2VY/3T | EVERLIGHT(台湾亿光) | LCSC | C72044 | 0 | -1 | 0.019
20 | 1650nm | LED7 | LED1206-RD | 1 | 19-217/R6C-AL1M2VY/3T | EVERLIGHT(台湾亿光) | LCSC | C72044 | 0 | -1 | 0.019
21 | 1720nm | LED8 | LED1206-RD | 1 | 19-217/R6C-AL1M2VY/3T | EVERLIGHT(台湾亿光) | LCSC | C72044 | 0 | -1 | 0.019
22 | LED-0603_R | LED9 | LED0603_RED | 1 | 19-217/R6C-AL1M2VY/3T | EVERLIGHT(台湾亿光) | LCSC | C72044 | 0 | -1 | 0.019
23 | 750 | R7 | R0603 | 1 |  |  |  |  | 2 | 1
24 | 4.7k | R8,R9 | R0603 | 2 |  |  |  |  | 2 | 0
25 | 70 | R10 | R0603 | 1 |  |  |  |  | 0 | -1
26 | NAU7802SGI | U2 | SOP-16_L9.9-W3.9-P1.27-LS6.0-BL | 1 | NAU7802SGI | NUVOTON(新唐) | LCSC | C2614351 | 3 | 2 | 2.455
27 | TLC59108IPWR | U3 | TSSOP-20_L6.5-W4.4-P0.65-LS6.4-BL | 1 | TLC59108IPWR | TI(德州仪器) | LCSC | C130031 | 0 | -1 | 1.605
28 | OPA2376AIDGKR | U1 | VSSOP-8_L3.0-W3.0-P0.65-LS4.9-BL | 1 | OPA2376AIDGKR | TI(德州仪器) | LCSC | C54292 | 0 | -1 | 2.388
example:
0 | Main Assembly | PROD-1000 | Smart Sensor Device |  |  |  |  | 1 | A |  | EA |  |  |  | Top-level assembly
1 | PCB Assembly | PCB-001 | Main Control Board |  |  |  |  | 1 | A | FR4 | EA | 15.00 | 15.00 | 21
2 | Electronic Component | IC-ATMEGA328 | Microcontroller | Microchip | ATMEGA328P-AU | Digi-Key | 556-ATMEGA328PAU-ND | 1 | C |  | EA | 2.50 | 2.50 | 14 | Critical component
2 | Electronic Component | RES-10K | Resistor 10KΩ 1% | Yageo | RC0603FR-0710KL | Mouser | 603-RC0603FR0710KL | 10 | C |  | EA | 0.01 | 0.10 | 7 | Common resistor
1 | Mechanical | ENC-PLSTC | Plastic Enclosure | ABC Plastics | ENC-1001 | Local Supplier |  | 1 | A | ABS | EA | 5.00 | 5.00 | 10 | Injection molded
1 | Fasteners | SCR-M3 | Screw M3x6 | BoltCo | SC-M3X6 | Bolt Depot | 12345 | 4 | A | Steel | EA | 0.05 | 0.20 | 3

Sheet: BOM loki original
Index | Quantity | Part Number | Manufacturer Part Number | Description | Customer Reference | Available | Backorder | Unit Price | Extended Price USD
1 | 20 | 311-1088-1-ND | CC0603KRX7R7BB104 | CAP CER 0.1UF 16V X7R 0603 |  | 20 | 0 | 0.042 | 0.84
2 | 20 | 1276-2310-1-ND | CL10C510JB8NNNC | CAP CER 51PF 50V C0G/NP0 0603 |  | 20 | 0 | 0.041 | 0.82
3 | 4 | 311-4019-1-ND | CC0603JRX7R9BB473 | CAP CER 0.047UF 50V X7R 0603 |  | 4 | 0 | 0.1 | 0.40
4 | 2 | 311-1446-1-ND | CC0603KRX7R7BB105 | CAP CER 1UF 16V X7R 0603 |  | 2 | 0 | 0.14 | 0.28
5 | 6 | 1276-1038-1-ND | CL10A106KQ8NNNC | CAP CER 10UF 6.3V X5R 0603 |  | 6 | 0 | 0.13 | 0.78
6 | 2 | 490-7611-1-ND | GRM188R60J226MEA0D | CAP CER 22UF 6.3V X5R 0603 |  | 2 | 0 | 0.22 | 0.44
7 | 2 | 160-1405-1-ND | LTST-C150KRKT | LED RED CLEAR 1206 SMD |  | 2 | 0 | 0.33 | 0.66
8 | 2 | 1080-1461-1-ND | EAHC2835WD6 | LED COOL WHITE 6500K 2SMD |  | 2 | 0 | 0.39 | 0.78
9 | 2 | 1516-1269-1-ND | QBLP650-IR3 | LED CHIP IR WLP 850NM 1206 SMD |  | 2 | 0 | 0.66 | 1.32
10 | 2 | 1080-1350-1-ND | IR11-21C/TR8 | EMITTER IR 940NM 65MA 1206 |  | 2 | 0 | 0.47 | 0.94
11 | 1 | 1125-1342-ND | MTSM5010-199-IR | SWIR EMITTER 1050NM 1206 SMD |  | 1 | 0 | 18.02 | 18.02
12 | 1 | 5242-OIS-1501300N-X-TCT-ND | OIS-150 1300N-X-T | SWIR EMITTER 1300NM 1206 SMD FLA |  | 1 | 0 | 7.09 | 7.09
13 | 1 | 1125-MTSM6014-194-IRCT-ND | MTSM6014-194-IR | SWIR EMITTER 1460NM 1206 SMD |  | 1 | 0 | 11.91 | 11.91
14 | 1 | 5242-OIS-1501550N-X-TCT-ND | OIS-150 1550N-X-T | SWIR EMITTER 1550NM 1206 SMD FLA |  | 1 | 0 | 7.09 | 7.09
15 | 1 | 1125-1354-ND | MTSM5016-199-IR | SWIR EMITTER 1650NM 1206 SMD |  | 1 | 0 | 20.36 | 20.36
16 | 1 | 1125-MTSM0012-194-IRCT-ND | MTSM0012-194-IR | SWIR EMITTER 1200NM 1206 SMD |  | 1 | 0 | 11.91 | 11.91
17 | 2 | BSS138DW-FDICT-ND | BSS138DW-7-F | MOSFET 2N-CH 50V 0.2A SOT363 |  | 2 | 0 | 0.46 | 0.92
18 | 20 | 311-240KHRCT-ND | RC0603FR-07240KL | RES 240K OHM 1% 1/10W 0603 |  | 20 | 0 | 0.019 | 0.38
19 | 20 | P301HCT-ND | ERJ-3EKF3010V | RES SMD 301 OHM 1% 1/10W 0603 |  | 20 | 0 | 0.03 | 0.60
20 | 2 | 4988-NRC12ZOTRFCT-ND | NRC12ZOTRF | RES SMT12060M2A |  | 2 | 0 | 0.11 | 0.22
21 | 20 | 311-10KGRCT-ND | RC0603JR-0710KL | RES 10K OHM 5% 1/10W 0603 |  | 20 | 0 | 0.015 | 0.30
22 | 20 | 311-1.00KHRCT-ND | RC0603FR-071KL | RES 1K OHM 1% 1/10W 0603 |  | 20 | 0 | 0.019 | 0.38
23 | 20 | P43.00BZCT-ND | ERJ-PA3J430V | RES SMD 43 OHM 5% 1/3W 0603 |  | 20 | 0 | 0.056 | 1.12
24 | 2 | NAU7802SGI-ND | NAU7802SGI | IC ADC 24BIT SIGMA-DELTA 16SOP |  | 2 | 0 | 1.73 | 3.46
25 | 1 | 1125-MTSM2601SMF1-100-ND | MTSM2601SMF1-100 | SENSOR PHOTODIODE 800-2600NM SMD |  | 1 | 0 | 32.12 | 32.12
26 | 2 | 296-36508-1-ND | TLC59208FIPWR | IC LED DRVR LIN PWM 50MA 16TSSOP |  | 2 | 0 | 1.87 | 3.74
27 | 1 | AS7341-DLGTCT-ND | AS7341-DLGT | SENSOR OPT AMBIENT 8OLGA |  | 1 | 0 | 9.36 | 9.36
28 | 1 | 1125-MTSM1346SMF1-100-ND | MTSM1346SMF1-100 | SENSOR PHOTODIODE 1300NM 6SMD |  | 1 | 0 | 29.03 | 29.03
29 | 2 | AP2120N-2.5TRG1DICT-ND | AP2120N-2.5TRG1 | IC REG LINEAR 2.5V 150MA SOT23 |  | 2 | 0 | 0.38 | 0.76
30 | 2 | 50-ECS-2520MVLC-049-BN-CT-ND | ECS-2520MVLC-049-BN-TR | XTAL OSC XO 4.9152MHZ CMOS SMD |  | 2 | 0 | 1.16 | 2.32
31 | 2 | AP2125N-1.8TRG1DICT-ND | AP2125N-1.8TRG1 | IC REG LINEAR 1.8V 300MA SOT23-3 |  | 2 | 0 | 0.37 | 0.74
32 | 10 | 1276-1008-1-ND | CL10C101JB8NNNC | CAP CER 100PF 50V C0G/NP0 0603 |  | 10 | 0 | 0.026 | 0.26
33 | 4 | 296-22564-1-ND | OPA2376AIDR | IC OPAMP GP 2 CIRCUIT 8SOIC |  | 4 | 0 | 2.74 | 10.96
34 | 4 | 455-SM04B-SRSS-TBCT-ND | SM04B-SRSS-TB | CONN HEADER SMD R/A 4POS 1MM |  | 4 | 0 | 0.6 | 2.40

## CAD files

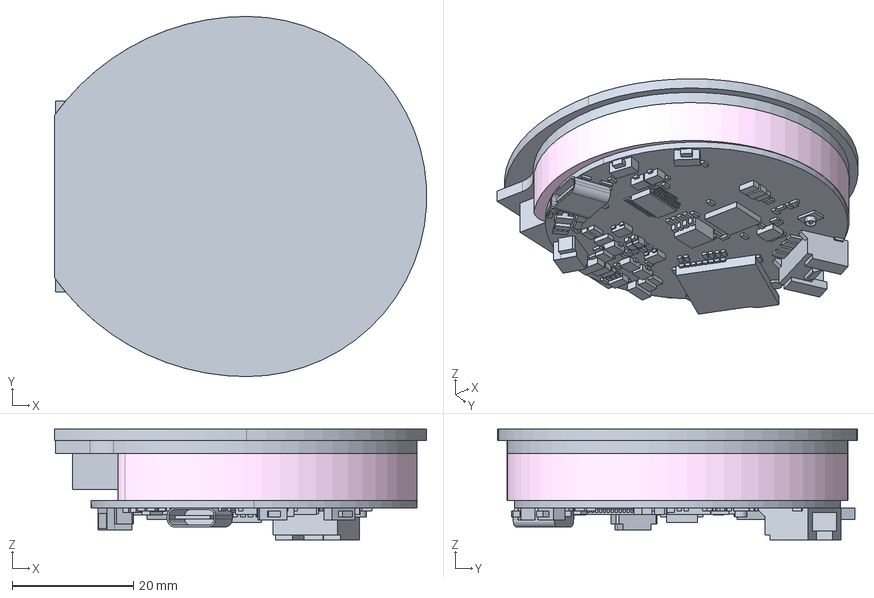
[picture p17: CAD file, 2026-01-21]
Firmware/Firmware Handheld Plastic Scanner LilyGo/dimensions/T-RGB-FULL-3D-2.1-Inches.stp
61.5 x 59.5 x 18.3 mm
LCD_BH021
T_RGB-V1_0
T_RGB_COVA

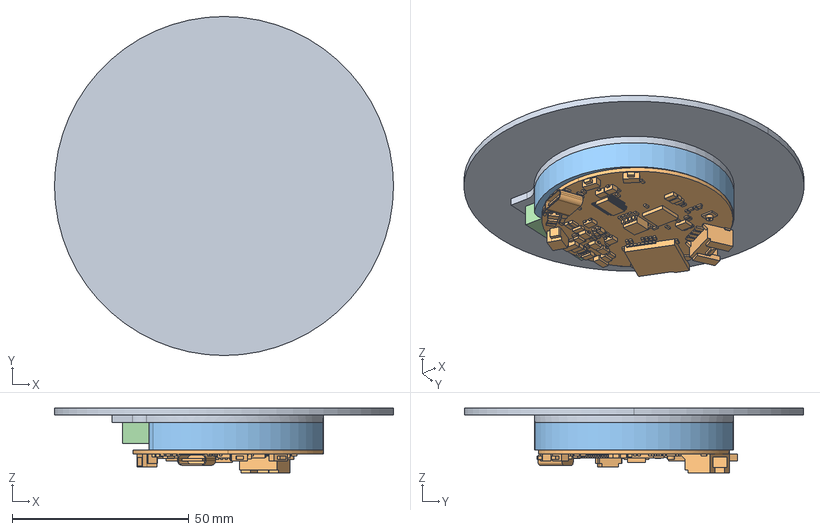
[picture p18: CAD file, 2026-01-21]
Firmware/Firmware Handheld Plastic Scanner LilyGo/dimensions/T-RGB-FULL-3D-2.8-Inches.stp
95.9 x 95.9 x 18.3 mm
LCD_BH021_2
T_RGB-V1_0_18
T_RGB_COVA_7

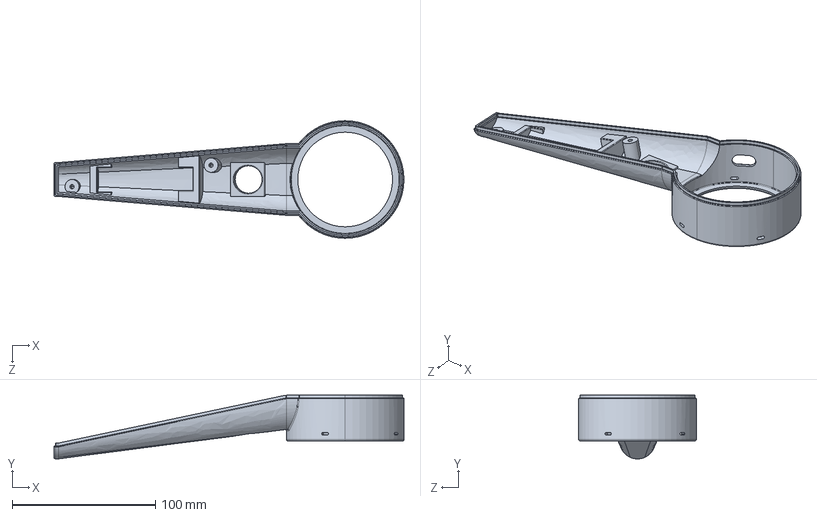
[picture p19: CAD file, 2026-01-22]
CAD/STEP files/top_shell_angle.STEP
244.0 x 44.5 x 82.0 mm

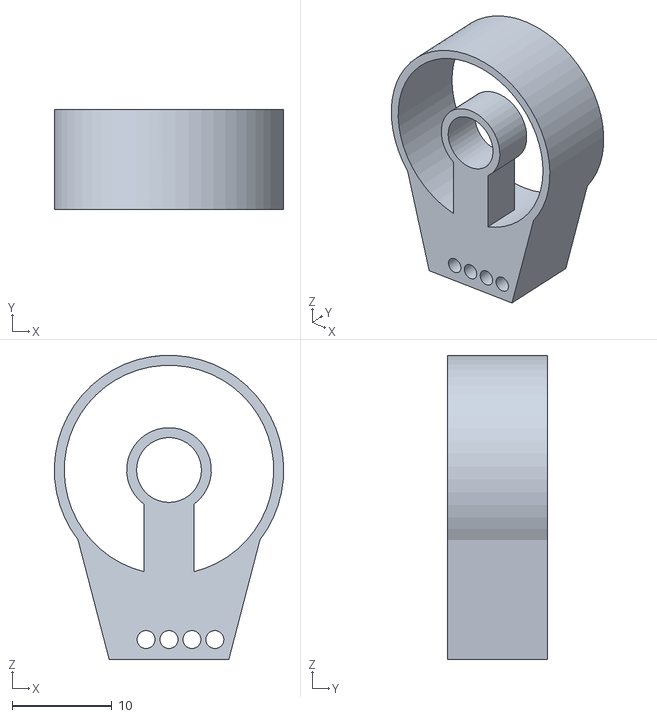
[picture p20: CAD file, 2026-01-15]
CAD/STL files/developmentboard_shield_LEDs.STL
23.0 x 10.0 x 30.5

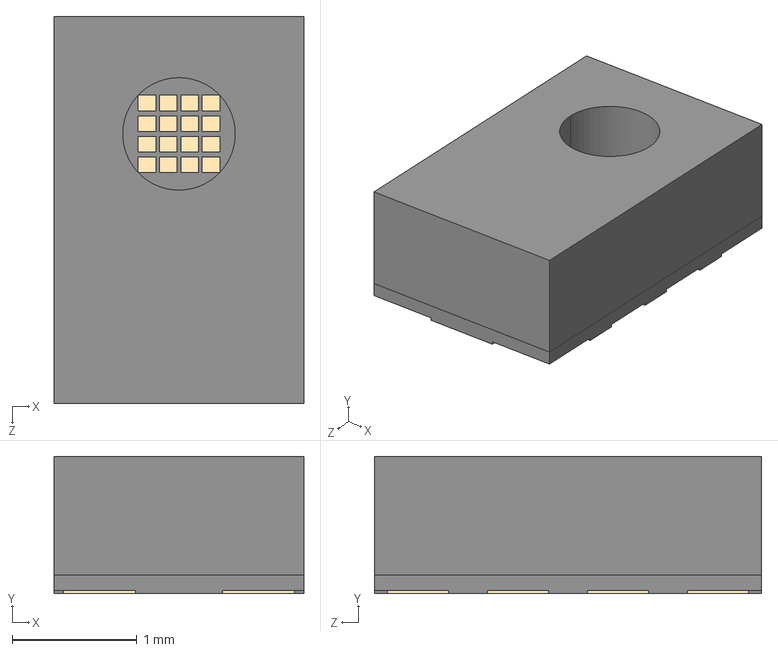
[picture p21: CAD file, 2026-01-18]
Hardware/Scanning PCB/RoundScanner_Ki_CAD_files/3dmodels/AS7341-DLGT.step
2.00 x 1.10 x 3.10 mm

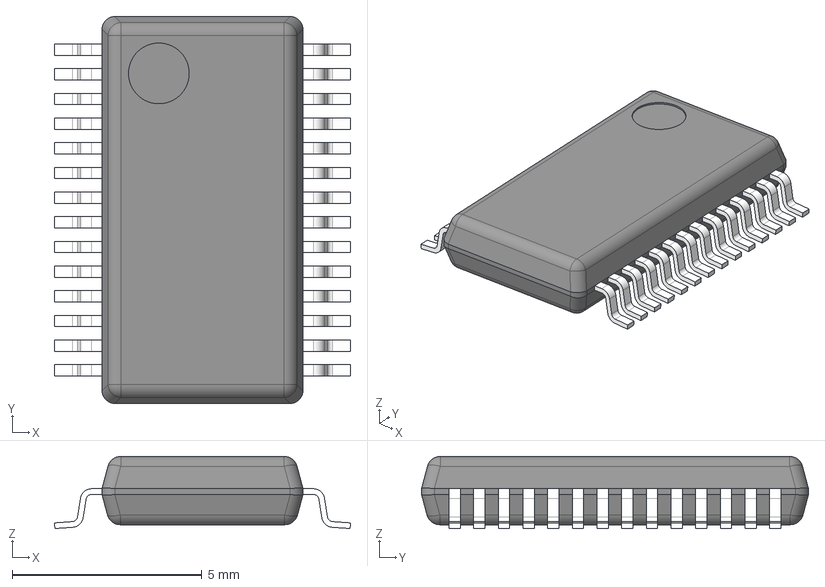
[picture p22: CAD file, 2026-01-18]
Hardware/Scanning PCB/RoundScanner_Ki_CAD_files/footprints/ADS1256IDBT/3D/ADS1256IDBT 2.stp
7.80 x 10.2 x 1.90 mm
BODY-SSOP
LEAD-SSOP x 28
PIN1

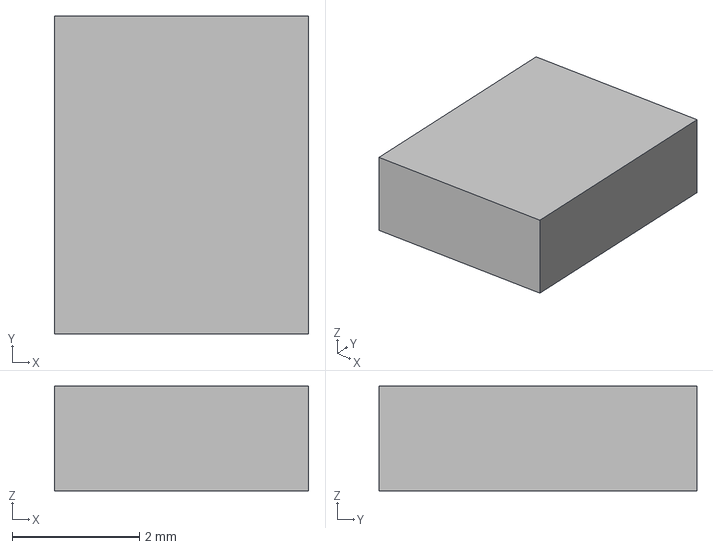
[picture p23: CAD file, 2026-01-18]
Hardware/Scanning PCB/RoundScanner_Ki_CAD_files/footprints/IC_Analog Devices_ADR03ARZ-REEL7/eec.models/Analog_Devices_-_ADR03ARZ-REEL7.step
4.00 x 5.00 x 1.65 mm

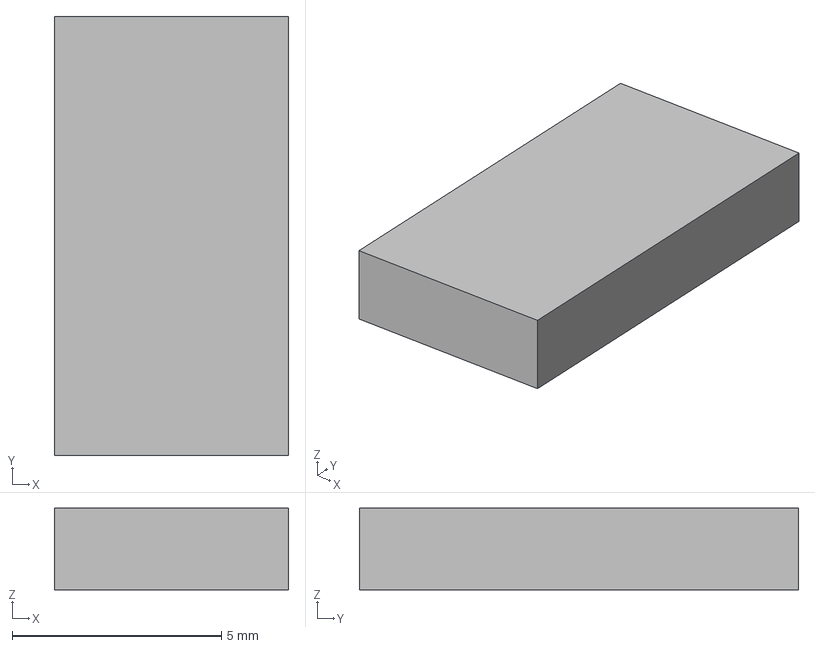
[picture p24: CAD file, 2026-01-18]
Hardware/Scanning PCB/RoundScanner_Ki_CAD_files/footprints/IC_Texas Instruments_ADS1256IDBT/eec.models/Texas_Instruments_-_ADS1256IDBT.step
5.60 x 10.5 x 1.95 mm

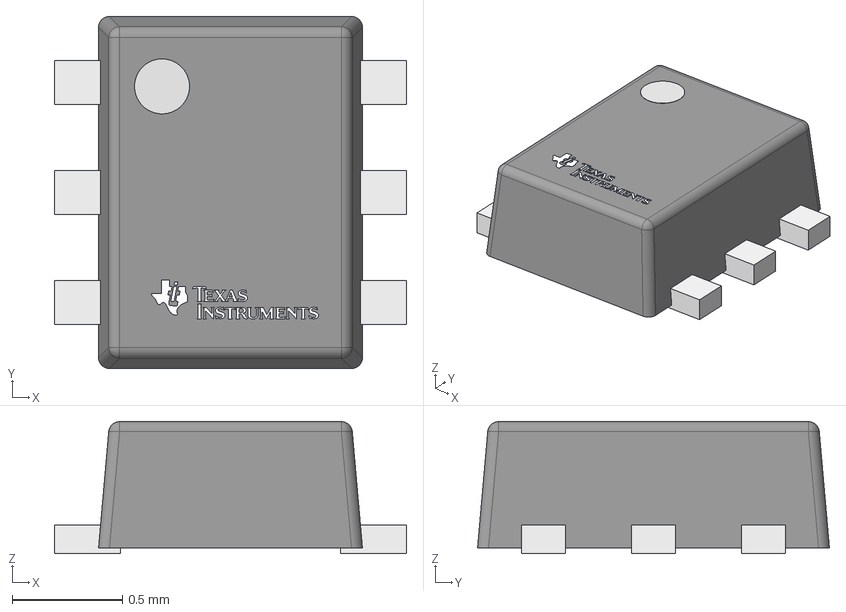
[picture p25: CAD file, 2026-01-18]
Hardware/Scanning PCB/RoundScanner_Ki_CAD_files/footprints/IC_Texas20Instruments_TPS61023DRLR-3/eec.models/Texas_Instruments_-_TPS61023DRLR.step
1.60 x 1.60 x 0.601 mm
FRAME-DRL0006A
BODY-SOT
circle
Texas Instruments

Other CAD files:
Hardware/Scanning PCB/RoundScanner_Ki_CAD_files/3dmodels/3D models LED's/C_0603_1608Metric_1.STEP.SLDASM
Hardware/Scanning PCB/RoundScanner_Ki_CAD_files/3dmodels/3D models LED's/LED_1206_3216Metric_1.STEP.SLDASM
Hardware/Scanning PCB/RoundScanner_Ki_CAD_files/3dmodels/3D models LED's/D_1206_3216Metric_1.STEP.SLDASM
Hardware/Scanning PCB/RoundScanner_Ki_CAD_files/3dmodels/3D models LED's/R_0603_1608Metric_1.STEP.SLDASM
Hardware/Scanning PCB/RoundScanner_Ki_CAD_files/3dmodels/3D models LED's/PinSocket_1x04_P2.54mm_Vertical_1.STEP.SLDASM
Hardware/Scanning PCB/RoundScanner_Ki_CAD_files/3dmodels/3D models LED's/LED_0805_2012Metric_1.STEP.SLDASM
Firmware/Firmware Handheld Plastic Scanner LilyGo/dimensions/ScreenSize.dwg
Hardware/Scanning PCB/RoundScanner_Ki_CAD_files/3dmodels/3D models LED's/SOLID-1_1.STEP.SLDPRT
CAD/STEP files/fixture_LCD.STEP
CAD/STEP files/low_shell_angle.STEP
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

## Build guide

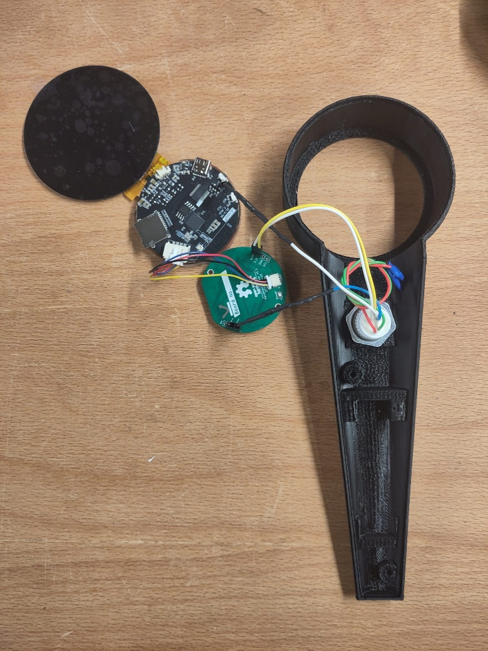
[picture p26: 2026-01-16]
CAD/Images/assembly.png

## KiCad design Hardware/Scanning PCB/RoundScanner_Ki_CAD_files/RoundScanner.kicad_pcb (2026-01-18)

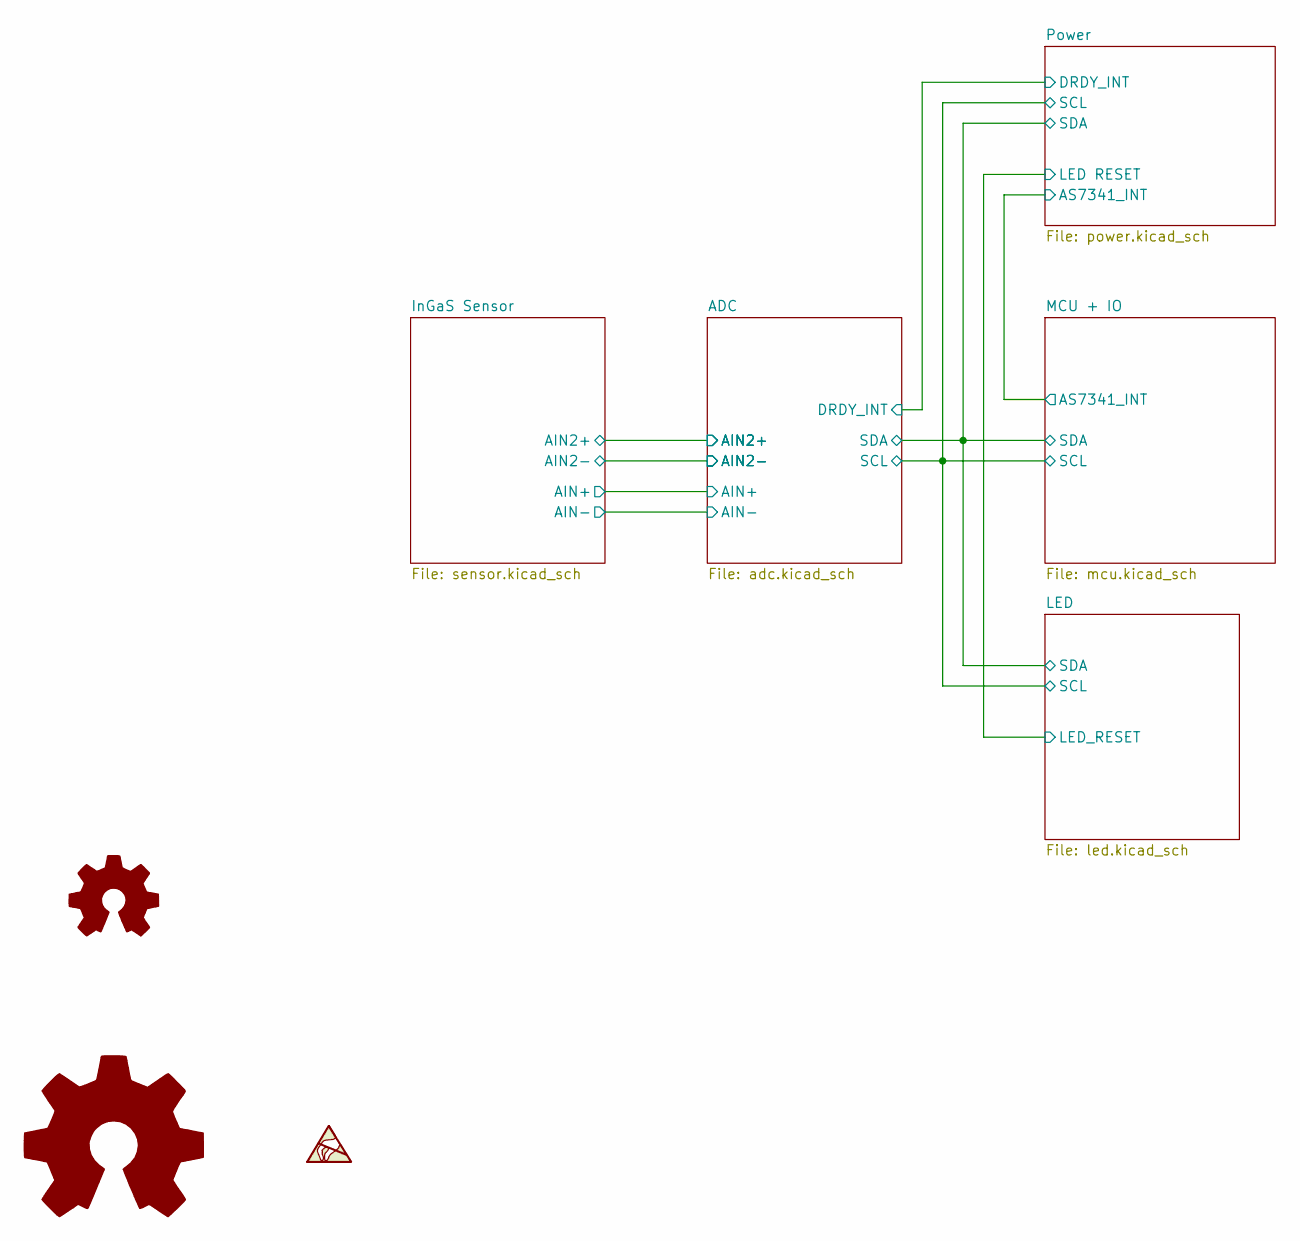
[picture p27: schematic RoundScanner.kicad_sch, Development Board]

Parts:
LOGO1: OSHW-Logo_11.4x12mm_SilkScreen
LOGO2: PlasticScannerLogo

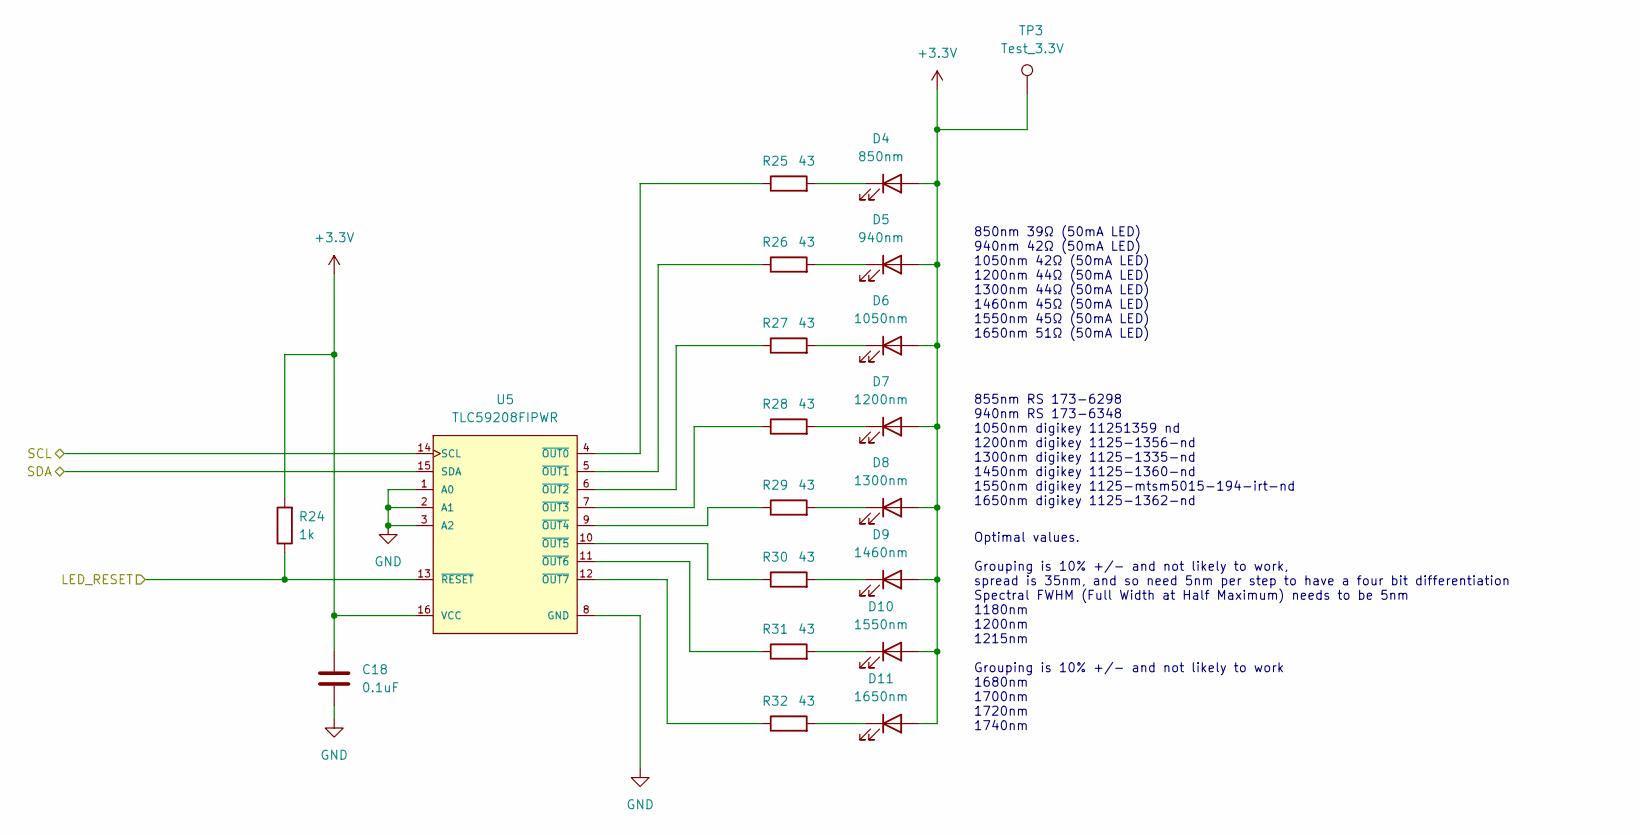
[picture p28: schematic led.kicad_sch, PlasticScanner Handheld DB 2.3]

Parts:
C18: 0.1uF; C_0603_1608Metric_Pad1.08x0.95mm_HandSolder; digikey description CAP CER 0.1UF 16V X7R 0603
D4: 850nm; LED_1206_3216Metric_Pad1.42x1.75mm_HandSolder; digikey part number 1516-1269-1-ND
D5: 940nm; LED_1206_3216Metric_Pad1.42x1.75mm_HandSolder; digikey part number 1080-1350-1-ND
D6: 1050nm; LED_1206_3216Metric_Pad1.42x1.75mm_HandSolder; digikey part number 1125-1342-ND
D7: 1200nm; LED_1206_3216Metric_Pad1.42x1.75mm_HandSolder; digikey part number 5242-OIS-1501300N-X-TCT-ND
D8: 1300nm; LED_1206_3216Metric_Pad1.42x1.75mm_HandSolder; digikey part number 1125-MTSM6014-194-IRCT-ND
D9: 1460nm; LED_1206_3216Metric_Pad1.42x1.75mm_HandSolder; digikey part number 5242-OIS-1501550N-X-TCT-ND
D10: 1550nm; LED_1206_3216Metric_Pad1.42x1.75mm_HandSolder; digikey part number 1125-1354-ND
D11: 1650nm; LED_1206_3216Metric_Pad1.42x1.75mm_HandSolder; digikey part number 1125-MTSM0012-194-IRCT-ND
R24: 1k; R_0603_1608Metric_Pad0.98x0.95mm_HandSolder; digikey description RES 1K OHM 1% 1/10W 0603
R25, R26, R27, R28, R29, R30, R31: 43; R_0603_1608Metric_Pad0.98x0.95mm_HandSolder; digikey description RES SMD 43 OHM 5% 1/3W 0603
R32: 43; R_0603_1608Metric_Pad0.98x0.95mm_HandSolder; mouser part number 667-ERJ-3EKF1300V; digikey description RES SMD 43 OHM 5% 1/3W 0603
TP3: Test_3.3V; TestPoint_Pad_D1.5mm
U5: TLC59208FIPWR; SOP65P640X120-16N; digikey description TLC59208FIPWR

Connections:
+3.3V: C18.1, D4.2 (A), D5.2 (A), D6.2 (A), D7.2 (A), D8.2 (A), D9.2 (A), D10.2 (A), D11.2 (A), R24.2, TP3.1, U5.16 (VCC); also elsewhere on the board
/LED/LED_RESET: R24.1, U5.13 (~RESET); also elsewhere on the board
GND: C18.2, U5.1 (A0), U5.2 (A1), U5.3 (A2), U5.8 (GND); also elsewhere on the board
unnamed: D4.1 (K), R25.2
unnamed: D5.1 (K), R26.2
unnamed: D6.1 (K), R27.2
unnamed: D7.1 (K), R28.2
unnamed: D8.1 (K), R29.2
unnamed: D9.1 (K), R30.2
unnamed: D10.1 (K), R31.2
unnamed: D11.1 (K), R32.2
unnamed: R25.1, U5.4 (~OUT0)
unnamed: R26.1, U5.5 (~OUT1)
unnamed: R27.1, U5.6 (~OUT2)
unnamed: R28.1, U5.7 (~OUT3)
unnamed: R29.1, U5.9 (~OUT4)
unnamed: R30.1, U5.10 (~OUT5)
unnamed: R31.1, U5.11 (~OUT6)
unnamed: R32.1, U5.12 (~OUT7)
SCL: U5.14 (SCL); also elsewhere on the board
SDA: U5.15 (SDA); also elsewhere on the board

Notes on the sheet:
855nm RS 173-6298 940nm RS 173-6348 1050nm digikey 11251359 nd 1200nm digikey 1125-1356-nd 1300nm digikey 1125-1335-nd 1450nm digikey 1125-1360-nd 1550nm digikey 1125-mtsm5015-194-irt-nd 1650nm digikey 1125-1362-nd
850nm 39Ω (50mA LED) 940nm 42Ω (50mA LED) 1050nm 42Ω (50mA LED) 1200nm 44Ω (50mA LED) 1300nm 44Ω (50mA LED) 1460nm 45Ω (50mA LED) 1550nm 45Ω (50mA LED) 1650nm 51Ω (50mA LED)
Optimal values. Grouping is 10% +/- and not likely to work, spread is 35nm, and so need 5nm per step to have a four bit differentiation Spectral FWHM (Full Width at Half Maximum) needs to be 5nm 1180nm 1200nm 1215nm Grouping is 10% +/- and not likely to work 1680nm 1700nm 1720nm 1740nm

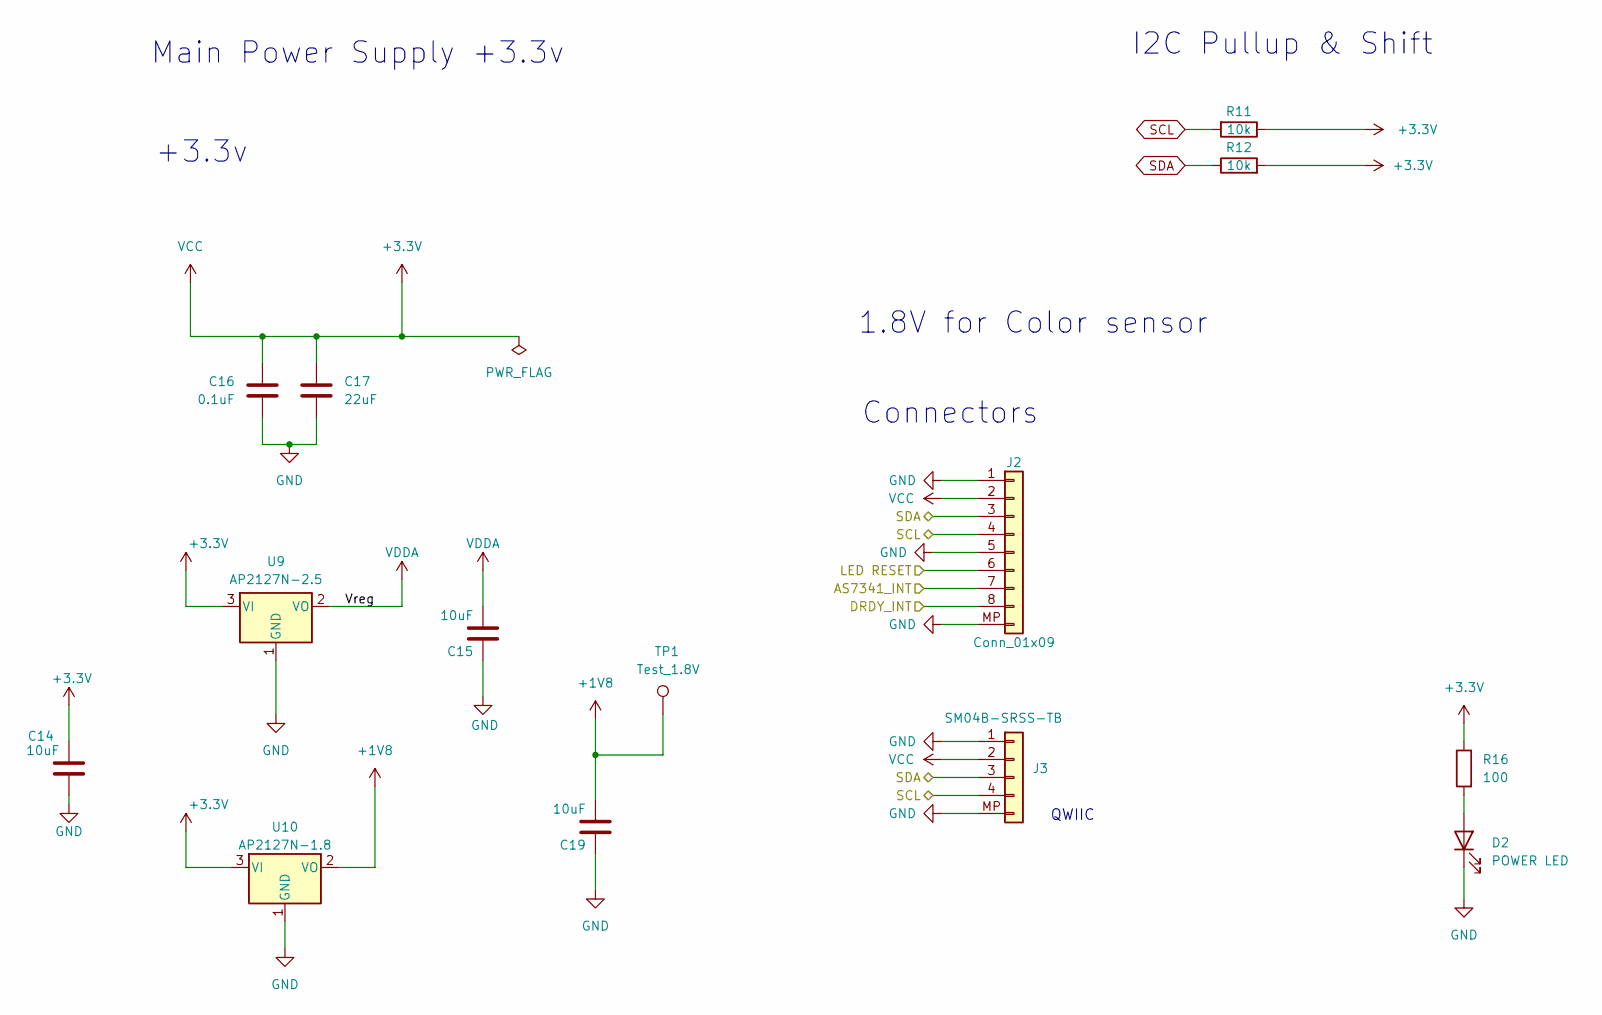
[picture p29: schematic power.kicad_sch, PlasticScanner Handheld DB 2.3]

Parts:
C14, C15, C19: 10uF; C_0603_1608Metric_Pad1.08x0.95mm_HandSolder; digikey description CAP CER 10UF 6.3V X5R 0603
C16: 0.1uF; C_0603_1608Metric_Pad1.08x0.95mm_HandSolder; digikey description CAP CER 0.1UF 16V X7R 0603
C17: 22uF; C_0603_1608Metric_Pad1.08x0.95mm_HandSolder; digikey description CAP CER 22UF 6.3V X5R 0603
D2: POWER LED; LED_0805_2012Metric_Pad1.15x1.40mm_HandSolder; digikey description LED RED CLEAR 1206 SMD
J2: Conn_01x09; round_notch
J3: SM04B-SRSS-TB; JST_SH_SM04B-SRSS-TB_1x04-1MP_P1.00mm_Horizontal; digikey description SM04B-SRSS-TB
R11, R12: 10k; R_0603_1608Metric_Pad0.98x0.95mm_HandSolder; mouser part number 279-CRGH0603J10K; mouser description CRGH0603J10K
R16: 100; R_0603_1608Metric_Pad0.98x0.95mm_HandSolder; digikey description RES 1K OHM 1% 1/10W 0603
TP1: Test_1.8V; TestPoint_Pad_D1.5mm
U9: AP2127N-2.5; SOT-23; digikey description IC REG LINEAR 2.5V 300MA SOT23
U10: AP2127N-1.8; SOT-23; digikey description IC REG LINEAR 1.8V 300MA SOT23-3

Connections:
+1V8: C19.2, TP1.1, U10.2 (VO); also elsewhere on the board
+3.3V: C14.2, C16.2, C17.1, J2.2, J3.2, R11.1, R12.2, R16.1, U9.3 (VI), U10.3 (VI); also elsewhere on the board
/ADC/DRDY_INT: J2.8; also elsewhere on the board
/LED/LED_RESET: J2.6; also elsewhere on the board
/MCU + IO/AS7341_INT: J2.7; also elsewhere on the board
GND: C14.1, C15.1, C16.1, C17.2, C19.1, D2.1 (K), J2.1, J2.5, J2.MP, J3.1, J3.MP (Pin_5), U9.1 (GND), U10.1 (GND); also elsewhere on the board
unnamed: D2.2 (A), R16.2
SCL: J2.4, J3.4, R11.2; also elsewhere on the board
SDA: J2.3, J3.3, R12.1; also elsewhere on the board
VDDA: C15.2, U9.2 (VO); also elsewhere on the board

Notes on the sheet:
Connectors
QWIIC
Main Power Supply +3.3v
1.8V for Color sensor
+3.3v
I2C Pullup & Shift

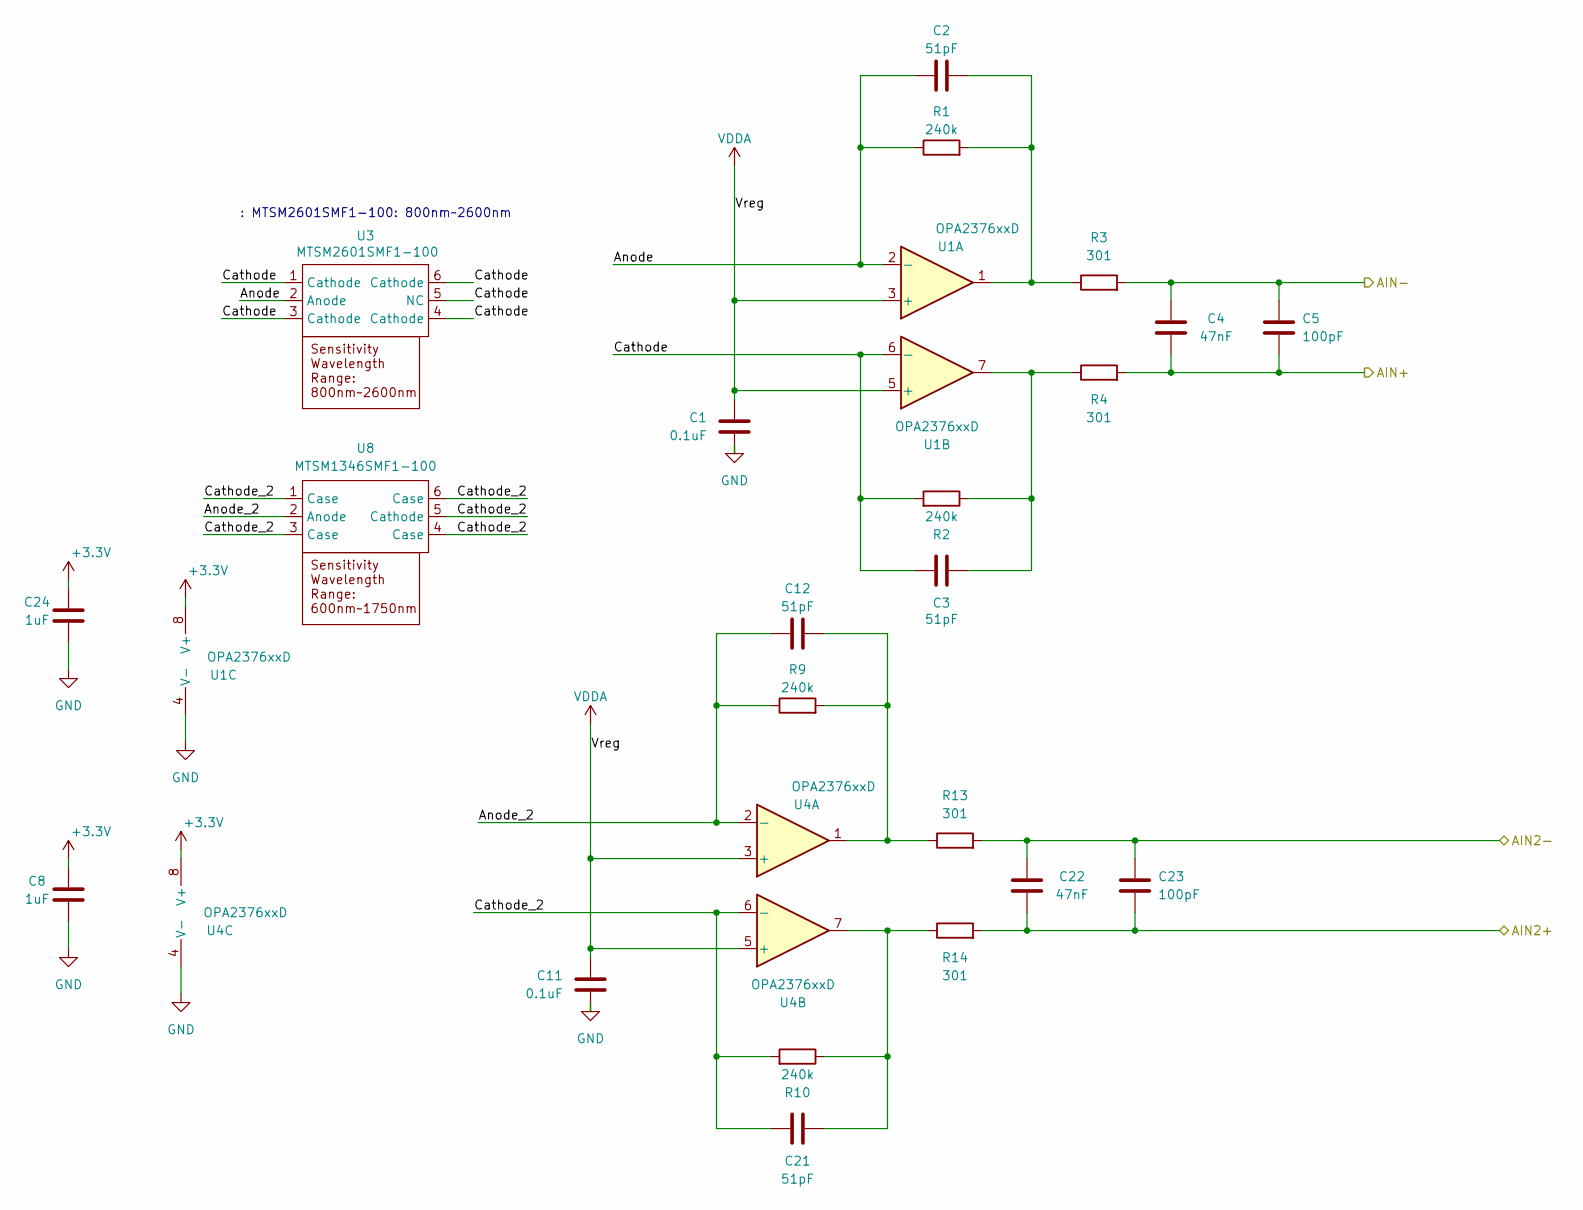
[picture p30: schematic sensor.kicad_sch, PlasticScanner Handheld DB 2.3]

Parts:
C1, C11: 0.1uF; C_0603_1608Metric_Pad1.08x0.95mm_HandSolder; digikey description CAP CER 0.1UF 16V X7R 0603
C2, C3, C12, C21: 51pF; C_0603_1608Metric_Pad1.08x0.95mm_HandSolder; digikey description CAP CER 51PF 50V C0G/NP0 0603
C4, C22: 47nF; C_0603_1608Metric_Pad1.08x0.95mm_HandSolder; digikey description CAP CER 0.047UF 50V X7R 0603
C5, C23: 100pF; C_0603_1608Metric_Pad1.08x0.95mm_HandSolder; digikey description CAP CER 100PF 50V C0G/NP0 0603
C8, C24: 1uF; C_0603_1608Metric_Pad1.08x0.95mm_HandSolder; digikey description CAP CER 1UF 16V X7R 0603
R1, R2, R9, R10: 240k; R_0603_1608Metric_Pad0.98x0.95mm_HandSolder; mouser part number 667-ERJ-3EKF2403V; mouser description ERJ-3EKF2403V
R3, R4, R13, R14: 301; R_0603_1608Metric_Pad0.98x0.95mm_HandSolder; mouser part number 667-ERJ-3EKF3010V; mouser description ERJ-3EKF3010V
U1, U4: OPA2376xxD; SOIC127P599X175-8N; mouser part number 595-OPA2376AIDR; digikey part number 296-26263-5-ND
U3: MTSM2601SMF1-100; digikey description SENSOR PHOTODIODE 800-2600NM SMD
U8: MTSM1346SMF1-100; digikey description SENSOR PHOTODIODE 1300NM 6SMD

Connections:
+3.3V: C8.2, C24.2, U1.8 (V+), U4.8 (V+); also elsewhere on the board
/ADC/AIN2+: C22.1, C23.2, R14.2; also elsewhere on the board
/ADC/AIN2-: C22.2, C23.1, R13.2; also elsewhere on the board
/ADC/AIN+: C4.1, C5.2, R4.2; also elsewhere on the board
/ADC/AIN-: C4.2, C5.1, R3.2; also elsewhere on the board
/InGaS Sensor/Anode: C2.1, R1.1, U1.2 (-), U3.2 (Anode)
/InGaS Sensor/Anode_2: C12.1, R9.1, U4.2 (-), U8.2 (Anode)
/InGaS Sensor/Cathode: C3.1, R2.2, U1.6 (-), U3.1 (Cathode), U3.3 (Cathode), U3.4 (Cathode), U3.5 (NC), U3.6 (Cathode)
/InGaS Sensor/Cathode_2: C21.1, R10.2, U4.6 (-), U8.1 (Case), U8.3 (Case), U8.4 (Case), U8.5 (Cathode), U8.6 (Case)
GND: C1.1, C8.1, C11.1, C24.1, U1.4 (V-), U4.4 (V-); also elsewhere on the board
unnamed: C2.2, R1.2, R3.1, U1.1
unnamed: C3.2, R2.1, R4.1, U1.7
unnamed: C12.2, R9.2, R13.1, U4.1
unnamed: C21.2, R10.1, R14.1, U4.7
VDDA: C1.2, C11.2, U1.3 (+), U1.5 (+), U4.3 (+), U4.5 (+); also elsewhere on the board

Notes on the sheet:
: MTSM2601SMF1-100: 800nm~2600nm

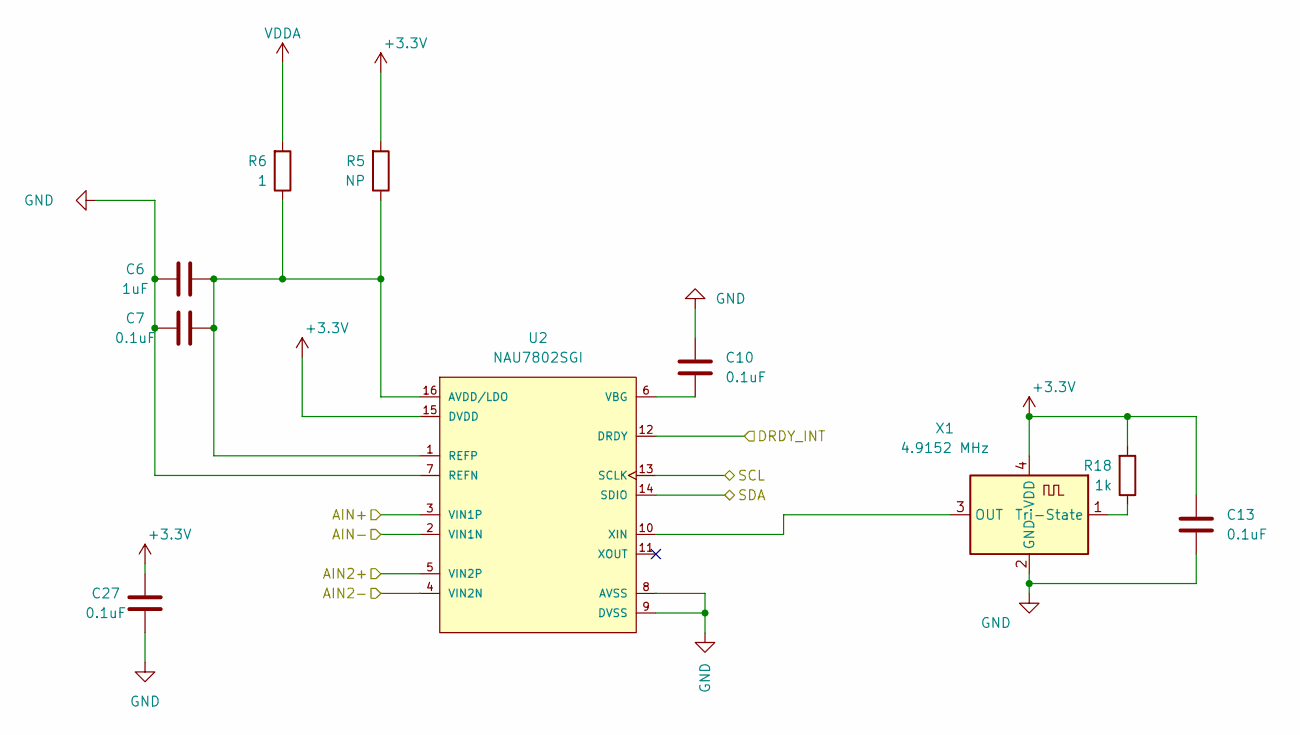
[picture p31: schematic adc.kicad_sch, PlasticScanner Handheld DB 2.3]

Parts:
C6: 1uF; C_0603_1608Metric_Pad1.08x0.95mm_HandSolder; digikey description CAP CER 1UF 16V X7R 0603
C7, C10, C13, C27: 0.1uF; C_0603_1608Metric_Pad1.08x0.95mm_HandSolder; digikey description CAP CER 0.1UF 16V X7R 0603
R5: NP; R_0603_1608Metric_Pad0.98x0.95mm_HandSolder
R6: 1; R_0603_1608Metric_Pad0.98x0.95mm_HandSolder; mouser part number 652-CHP0603QFW-1R00E; mouser description CHP0603QFW-1R00ELF
R18: 1k; R_0603_1608Metric_Pad0.98x0.95mm_HandSolder; digikey description RES 1K OHM 1% 1/10W 0603
U2: NAU7802SGI; Nuvoton-NAU7802SGI; digikey description IC ADC 24BIT I2C/SRL 16-SOP
X1: 4.9152 MHz; Oscillator_SMD_ECS_2520MV-xxx-xx-4Pin_2.5x2.0mm; digikey description XTAL OSC XO 4.9152MHZ CMOS SMD

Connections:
+3.3V: C13.1, C27.2, R5.2, R18.2, U2.15 (DVDD), X1.4 (VDD); also elsewhere on the board
/ADC/AIN2+: U2.5 (VIN2P); also elsewhere on the board
/ADC/AIN2-: U2.4 (VIN2N); also elsewhere on the board
/ADC/AIN+: U2.3 (VIN1P); also elsewhere on the board
/ADC/AIN-: U2.2 (VIN1N); also elsewhere on the board
/ADC/DRDY_INT: U2.12 (DRDY); also elsewhere on the board
GND: C6.1, C7.1, C10.1, C13.2, C27.1, U2.7 (REFN), U2.8 (AVSS), U2.9 (DVSS), X1.2 (GND); also elsewhere on the board
unnamed: C6.2, C7.2, R5.1, R6.1, U2.1 (REFP), U2.16 (AVDD/LDO)
unnamed: C10.2, U2.6 (VBG)
unnamed: U2.10 (XIN), X1.3 (OUT)
unnamed: R18.1, X1.1 (Tri-State)
SCL: U2.13 (SCLK); also elsewhere on the board
SDA: U2.14 (SDIO); also elsewhere on the board
VDDA: R6.2; also elsewhere on the board

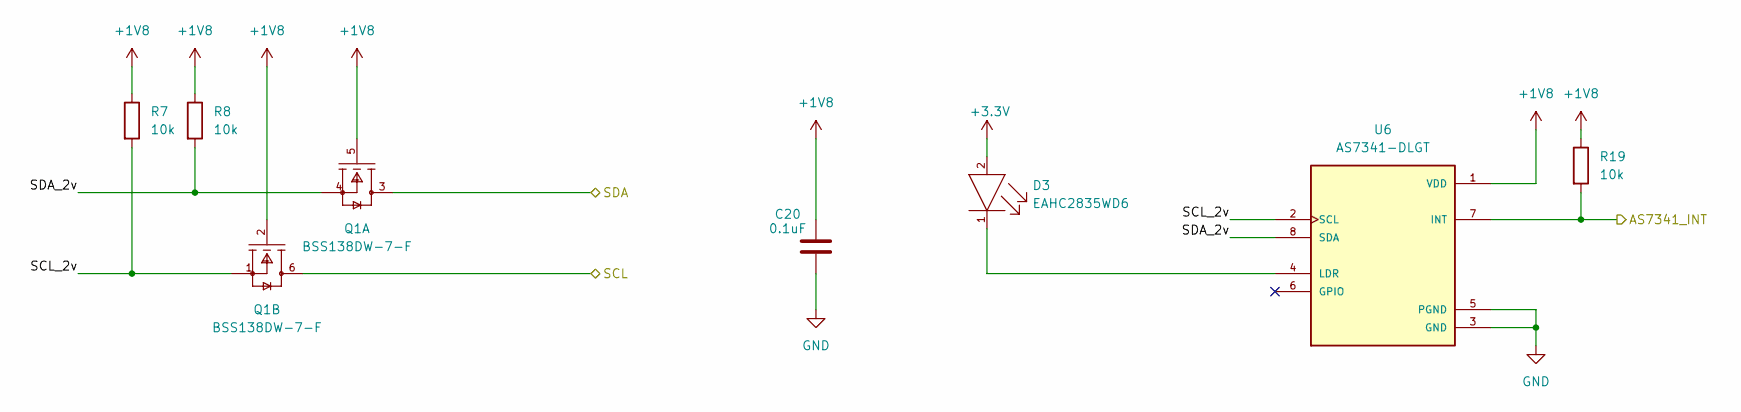
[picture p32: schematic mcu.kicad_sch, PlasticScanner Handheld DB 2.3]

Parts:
C20: 0.1uF; C_0603_1608Metric_Pad1.08x0.95mm_HandSolder; digikey description CAP CER 0.1UF 16V X7R 0603
D3: EAHC2835WD6; Everlight-EAHC2835WD6-MFG; mouser part number 638-EAHC2835WD6; digikey description LED COOL WHITE 6500K 2SMD
Q1: BSS138DW-7-F; Diodes_Inc._-_BSS138DW-7-F-A; mouser part number 621-BSS138DW-F; digikey description MOSFET 2N-CH 50V 0.2A SC70-6
R7, R8, R19: 10k; R_0603_1608Metric_Pad0.98x0.95mm_HandSolder; mouser part number 279-CRGH0603J10K; mouser description CRGH0603J10K
U6: AS7341-DLGT; PSON80P310X200X110-8N; PARTREV V3; digikey description SENSOR OPT AMBIENT 8OLGA

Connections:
+1V8: C20.2, Q1.2 (G2), Q1.5 (G1), R7.1, R8.1, R19.1, U6.1 (VDD); also elsewhere on the board
+3.3V: D3.2 (ANODE); also elsewhere on the board
/MCU + IO/AS7341_INT: R19.2, U6.7 (INT); also elsewhere on the board
/MCU + IO/SCL_2v: Q1.1 (S2), R7.2, U6.2 (SCL)
/MCU + IO/SDA_2v: Q1.4 (S1), R8.2, U6.8 (SDA)
GND: C20.1, U6.3 (GND), U6.5 (PGND); also elsewhere on the board
unnamed: D3.1 (CATHODE), U6.4 (LDR)
SCL: Q1.6 (D2); also elsewhere on the board
SDA: Q1.3 (D1); also elsewhere on the board

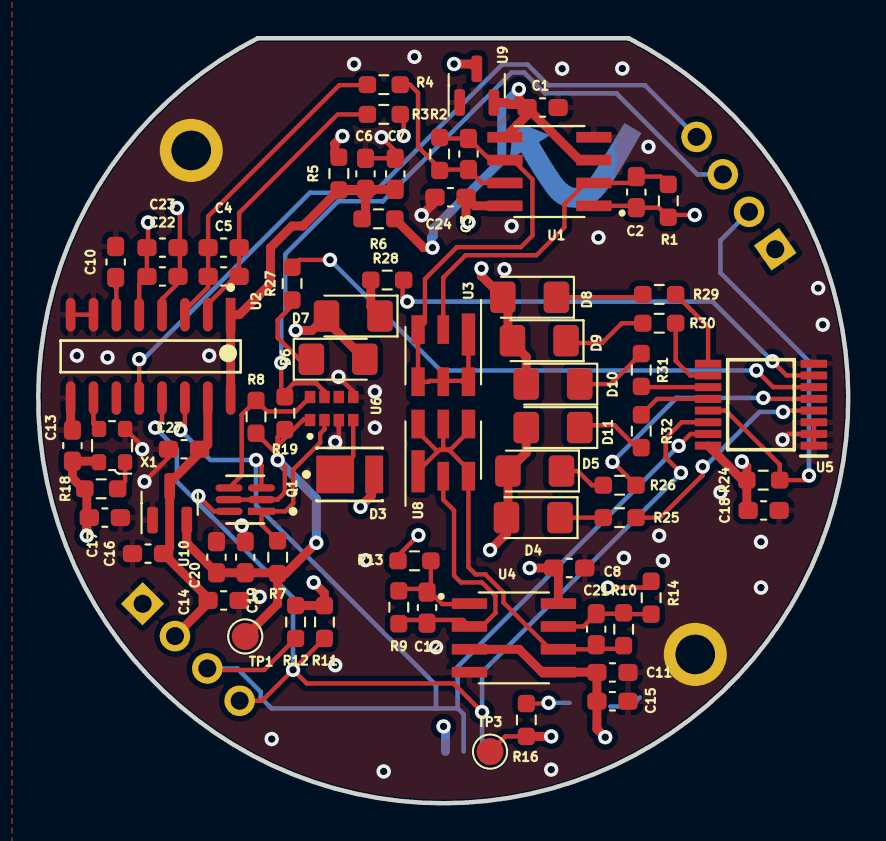
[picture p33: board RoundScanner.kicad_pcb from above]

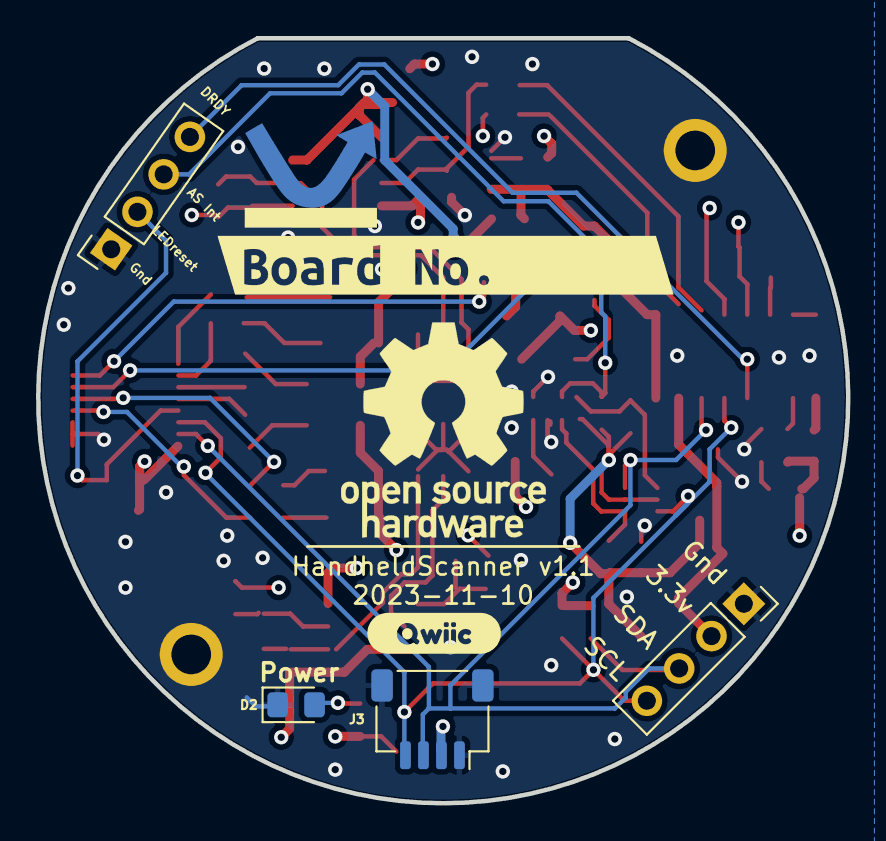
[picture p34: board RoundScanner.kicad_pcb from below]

Board: 4 copper layers, 45.0 x 42.5 mm, 79 parts (6 on the bottom side), 45 nets.

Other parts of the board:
kibuzzard-6398DD41: G***; kibuzzard-6398DD41
kibuzzard-6346913B: G***; kibuzzard-6346913B

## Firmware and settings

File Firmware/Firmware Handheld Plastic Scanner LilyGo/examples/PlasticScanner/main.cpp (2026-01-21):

#include "tlc59208.h"
#include <LilyGo_RGBPanel.h>
#include <LV_Helper.h>
#include <Wire.h>
#include <Arduino.h>
#include <SparkFun_Qwiic_Scale_NAU7802_Arduino_Library.h>
#include <EloquentTinyML.h>
#include "barbie.h"
#include "ps_logo.h"
#include <Adafruit_AS7341.h>
#include <EEPROM.h> 


#define N_INPUTS 8 // darkreading + 7 leds, no color sensor for now
#define N_RESULTS 6
#define TENSOR_ARENA_SIZE 2 * 1024
#define N_OUTPUTS 7 // number of LEDs
#define RESET 2
#define ADDR 0x20
#define UI_BUTTON_PIN 0   // GPIO0 (BOOT)

// Time thresholds
#define SHORT_PRESS_MS 50      // min duration for a "short press"
#define LONG_PRESS_MS 2000     // min duration for "long press" to enter sleep
#define IDLE_TIMEOUT_MS (5 * 60 * 1000UL)  // 5 minutes idle timeout
#define RESULTS_DISPLAY_MS (1 * 60 * 1000UL)  // Results display timeout (1 minute)

NAU7802 nau;
TLC59208 tlc;
LilyGo_RGBPanel panel;
Adafruit_AS7341 as7341;

Eloquent::TinyML::TfLite<N_INPUTS, N_RESULTS, TENSOR_ARENA_SIZE> tf;
float baseline[N_OUTPUTS]; // store calibration readings
bool calibrated = false;

volatile bool scanRunning = false;
RTC_DATA_ATTR int bootCount = 0;
unsigned long lastActivity = 0;

//plastic scanner logo
lv_obj_t *logo_img = nullptr;
lv_timer_t *splash_timer = nullptr;
lv_timer_t *results_timer = nullptr;  // Timer to auto-return to main UI after results

//storage for results
long darkReading = 0;
lv_obj_t *titleLabel;
long ledReadings[N_OUTPUTS];
long val;
int scanIndex = 0;

// conversion of raw readings
double allReadings[9]; // combined IR + color readings
float input[N_INPUTS];

//same as in training model
const char* PLASTIC_NAMES[] = {
    "PP",
    "PS",
    "PET",
    "HDPE",
    "PVC",
    "LDPE"
};

static const int NUM_PLASTICS = sizeof(PLASTIC_NAMES) / sizeof(PLASTIC_NAMES[0]);
// Confidence thresholds
#define CONFIDENCE_MIN 0.50f      // minimum probability to accept result
#define CONFIDENCE_GAP 0.15f      // gap between best and second-best

// UI Customization
#define MAIN_RESULT_FONT &lv_font_montserrat_40    // Font size for main prediction
#define PROB_FONT &lv_font_montserrat_24           // Font size for class probabilities
#define RESULT_Y_OFFSET -40                         // Y offset for main result from center (negative = up)
#define LINE_Y_OFFSET 20                            // Y offset of divider from main result
#define PROB_START_OFFSET 10                        // Y offset where probabilities start from divider
#define PROB_SPACING 30                             // Vertical spacing between probability labels

float lastResults[N_RESULTS];
int predictedIndex = -1;
float predictedConfidence = 0.0f;
bool predictionInconclusive = true;

void interpretResults(float* results) {
    int best = 0;
    int second = -1;

    for (int i = 1; i < N_RESULTS; i++) {
        if (results[i] > results[best]) {
            second = best;
            best = i;
        } else if (second < 0 || results[i] > results[second]) {
            second = i;
        }
    }

    float bestVal = results[best];
    float secondVal = (second >= 0) ? results[second] : 0.0f;

    predictedIndex = best;
    predictedConfidence = bestVal;

    // Inconclusive logic
    predictionInconclusive =
        (bestVal < CONFIDENCE_MIN) ||
        ((bestVal - secondVal) < CONFIDENCE_GAP);
}


// Beer's law + normalization
void preprocessInput() {
    float ratios[N_INPUTS];

    // --- Beer's law ratios ---
    ratios[0] = (darkReading != 0) ? 
                ((float)ledReadings[0] / (float)darkReading) : 0.0f;

    for (int i = 1; i < N_OUTPUTS; i++) {
        ratios[i] = (ledReadings[i - 1] != 0) ?
                    ((float)ledReadings[i] / (float)ledReadings[i - 1]) : 0.0f;
    }

    // Fill remaining inputs if any
    for (int i = N_OUTPUTS; i < N_INPUTS; i++) {
        ratios[i] = 0.0f;
    }

    // --- Find per-scan min/max ---
    float minVal = ratios[0];
    float maxVal = ratios[0];

    for (int i = 1; i < N_INPUTS; i++) {
        if (ratios[i] < minVal) minVal = ratios[i];
        if (ratios[i] > maxVal) maxVal = ratios[i];
    }

    // Prevent divide-by-zero
    float range = maxVal - minVal;
    if (range < 1e-6f) range = 1.0f;

    // --- Normalize per scan ---
    for (int i = 0; i < N_INPUTS; i++) {
        input[i] = (ratios[i] - minVal) / range;

        // Clamp (safety)
        if (input[i] < 0.0f) input[i] = 0.0f;
        if (input[i] > 1.0f) input[i] = 1.0f;
    }

    // Debug
    Serial.print("min=");
    Serial.print(minVal, 6);
    Serial.print(" max=");
    Serial.println(maxVal, 6);
}

// Enter deep sleep
void goToDeepSleep() {
    Serial.println("Entering deep sleep. Press BOOT button (GPIO0) to wake.");

    // Wait until button released to avoid glitches
    while (digitalRead(UI_BUTTON_PIN) == LOW) {
        delay(10);
        Serial.flush();
    }

    delay(50); // small debounce

    // EXT1 wake: wake when GPIO0 is LOW
    esp_sleep_enable_ext1_wakeup(1ULL << GPIO_NUM_0, ESP_EXT1_WAKEUP_ANY_LOW);

    esp_deep_sleep_start();
}

void calibrate() {
    Serial.println("Place spectralon and press button...");
    delay(500); // let user settle
    for (int i = 0; i < N_OUTPUTS; i++) {
        baseline[i] = nau.getReading();
        Serial.print("Baseline LED "); Serial.print(i); Serial.print(": "); Serial.println(baseline[i]);
    }
    calibrated = true;
}

//plastic scanner logo
void createMainUI() {
    lv_obj_set_style_bg_color(lv_scr_act(), lv_color_hex(0xFFFFFF), 0); // black background

    lv_obj_clean(lv_scr_act());

    lv_obj_t *label = lv_label_create(lv_scr_act());
    lv_label_set_text(label, "Hello PlasticScanner");
    lv_obj_center(label);
    lv_obj_set_style_text_font(label, &lv_font_montserrat_32, 0); //32px

    lv_obj_t *btn = lv_btn_create(lv_scr_act());
    lv_obj_set_size(btn, 120, 50);
    lv_obj_align_to(btn, label, LV_ALIGN_OUT_BOTTOM_MID, 0, 0);

    lv_obj_t *btn_label = lv_label_create(btn);
    lv_label_set_text(btn_label, "Start Scan");
    lv_obj_center(btn_label);
}

void splashTimeout(lv_timer_t *timer) {
    if (timer) {
        lv_timer_del(timer);
    }
    splash_timer = nullptr;

    if (logo_img != nullptr) {
        lv_obj_del(logo_img);
    }
    logo_img = nullptr;

    createMainUI();
}

// Return to main UI after results display timeout
void resultsTimeout(lv_timer_t *timer) {
    if (timer) {
        lv_timer_del(timer);
    }
    results_timer = nullptr;

    createMainUI();
}


//result UI
void createResultsUI() {
    lv_obj_clean(lv_scr_act());

    // Background color logic 
    lv_color_t bg;

    Serial.print("DEBUG: predictionInconclusive="); Serial.print(predictionInconclusive);
    Serial.print(" predictedConfidence="); Serial.println(predictedConfidence, 3);

    if (predictionInconclusive) {
        bg = lv_color_hex(0xFF0000); // red (pure red)
        Serial.println("Setting RED");
    } else if (predictedConfidence < 0.60f) {
        bg = lv_color_hex(0xFF8000); // orange
        Serial.println("Setting ORANGE");
    } else {
        bg = lv_color_hex(0x00FF00); // green (pure green)
        Serial.println("Setting GREEN");
    }

    lv_obj_set_style_bg_color(lv_scr_act(), bg, 0);
    lv_obj_set_style_bg_opa(lv_scr_act(), LV_OPA_COVER, 0);

    // Main result label - centered in middle of screen
    lv_obj_t *result = lv_label_create(lv_scr_act());
    lv_obj_set_width(result, LV_PCT(100));
    lv_obj_set_style_text_align(result, LV_TEXT_ALIGN_CENTER, 0);
    lv_obj_set_style_text_color(result, lv_color_black(), 0);
    lv_obj_set_style_text_font(result, MAIN_RESULT_FONT, 0);

    if (predictionInconclusive) {
        lv_label_set_text(result, "INCONCLUSIVE");
    } else {
        lv_label_set_text_fmt(
            result,
            "%s\n%.0f%%",
            PLASTIC_NAMES[predictedIndex],
            predictedConfidence * 100.0f
        );
    }

    lv_obj_align(result, LV_ALIGN_CENTER, 0, RESULT_Y_OFFSET);

    //  Divider 
    lv_obj_t *line = lv_line_create(lv_scr_act());
    static lv_point_t line_points[] = {{10, 0}, {230, 0}};
    lv_line_set_points(line, line_points, 2);
    lv_obj_align_to(line, result, LV_ALIGN_OUT_BOTTOM_MID, 0, LINE_Y_OFFSET);
    lv_obj_set_style_line_color(line, lv_color_black(), 0);
    lv_obj_set_style_line_width(line, 2, 0);

    // Class probabilities 
    for (int i = 0; i < N_RESULTS; i++) {
        lv_obj_t *l = lv_label_create(lv_scr_act());
        lv_obj_set_width(l, LV_PCT(100));
        lv_label_set_text_fmt(
            l,
            "%s: %.1f%%",
            PLASTIC_NAMES[i],
            lastResults[i] * 100.0f
        );
        lv_obj_set_style_text_align(l, LV_TEXT_ALIGN_CENTER, 0);
        lv_obj_set_style_text_color(l, lv_color_black(), 0);
        lv_obj_set_style_text_font(l, PROB_FONT, 0);
        lv_obj_align_to(l, line, LV_ALIGN_OUT_BOTTOM_MID, 0, PROB_START_OFFSET + i * PROB_SPACING);
    }
}



//loading UI
void createLoadingUI() {
    lv_obj_clean(lv_scr_act());

    lv_obj_t *label = lv_label_create(lv_scr_act());
    lv_obj_set_style_bg_color(lv_scr_act(), lv_color_hex(0xFFFFFF), 0); 
    lv_label_set_text(label, "Scanning...");
    lv_obj_set_style_text_font(label, &lv_font_montserrat_32, 0); 
    lv_obj_center(label);
}


// Reset TLC59208
static void resetTLC() {
    digitalWrite(RESET, LOW);
    delayMicroseconds(1);
    digitalWrite(RESET, HIGH);
    delayMicroseconds(1);
}

// Softmax function
void softmax(float* x, int n) {
    float maxVal = x[0];
    for (int i = 1; i < n; i++) {
        if (x[i] > maxVal) maxVal = x[i];
    }

    float sum = 0.0f;
    for (int i = 0; i < n; i++) {
        x[i] = expf(x[i] - maxVal);  // numerical stability
        sum += x[i];
    }

    for (int i = 0; i < n; i++) {
        x[i] /= sum;
    }
}


// Run scan
void runScan() {
    scanRunning = true;
    Serial.println("Starting scan.");

    darkReading = nau.getReading();
    Serial.print("Dark reading: "); Serial.println(darkReading);
    delay(500);

    for (int i = 0; i < N_OUTPUTS; i++) {
        tlc.on(i);
        delay(10);
        ledReadings[i] = nau.getReading();
        Serial.print("LED "); Serial.print(i); Serial.print(" reading: "); Serial.println(ledReadings[i]);
        delay(50);
        resetTLC(); //new
        tlc.begin(); // do not call tlc.off(i) makes UI crash, but tlc.begin() works as well for tuning
        // Only call lv_timer_handler every other iteration to avoid stack issues
        if (i % 2 == 0) {
            lv_timer_handler();
        }
    }

    // Final lv_timer_handler call
    lv_timer_handler();

    // Preprocess input 
    preprocessInput();

    float results[N_RESULTS];

    Serial.println("Normalized input:");
    for (int i = 0; i < N_INPUTS; i++) {
        Serial.print(input[i], 6);
        Serial.print(", ");
    }
    Serial.println();


    Serial.println("Predicting material...");
    tf.predict(input, results);
    softmax(results, N_RESULTS);

    //float predicted = tf.predict(input);
    Serial.print("ML output: "); //Serial.println(predicted);
    // Print all probabilities
    for (int i = 0; i < N_RESULTS; i++) {
        Serial.print("Class ");
        Serial.print(i);
        Serial.print(": ");
        Serial.println(results[i], 6);
    }

    // Store results
    for (int i = 0; i < N_RESULTS; i++) {
        lastResults[i] = results[i];
    }

    // Interpret
    interpretResults(results);

    scanRunning = false;
    
}


// Setup
void setup() {
    Serial.begin(115200);
    delay(2000);
    bootCount++;
    Serial.print("Boot number: "); Serial.println(bootCount);

    pinMode(RESET, OUTPUT);
    pinMode(UI_BUTTON_PIN, INPUT_PULLUP);

    lastActivity = millis();

    // Initialize display
    if (!panel.begin()) {
        while (1) {
            Serial.println("Error initializing T-RGB");
            delay(1000);
        }
    }

    beginLvglHelper(panel);

    lv_obj_set_style_bg_color(lv_scr_act(), lv_color_hex(0x000000), 0);
    lv_obj_set_style_bg_opa(lv_scr_act(), LV_OPA_COVER, 0);

    // Show splash logo
    logo_img = lv_img_create(lv_scr_act());
    lv_img_set_src(logo_img, &ps_logo);
    lv_obj_set_style_img_recolor(logo_img, lv_color_hex(0xFF0000), 0);  // Red color for logo
    lv_obj_center(logo_img);
    lv_img_set_zoom(logo_img, 128);  // 256 = 100%, 192 ≈ 75%, 128 = 50%
    lv_obj_center(logo_img); //re center after scaling


    // Start 5s timer
    splash_timer = lv_timer_create(splashTimeout, 5000, nullptr);

    panel.setBrightness(10);

    Wire.begin();
    Wire.setClock(100000);  // Slow down I2C to 100kHz to prevent bus conflicts
    nau.begin();
    tlc.begin();
    tf.begin(barbie);


    if (nau.begin() == false) {
        Serial.println("NAU7802 not detected.");
    } else {
        Serial.println("NAU7802 detected!");
        nau.setGain(NAU7802_GAIN_4);
    }
}


// Main loop
void loop() {
    lv_timer_handler();

    // Handle GPIO0 press for short vs long press
    static bool lastButtonState = HIGH;
    static unsigned long pressStart = 0;

    bool buttonState = digitalRead(UI_BUTTON_PIN);
    unsigned long now = millis();

    // Button pressed
    if (lastButtonState == HIGH && buttonState == LOW) {
        pressStart = now;
    }

    // Button released
    if (lastButtonState == LOW && buttonState == HIGH) {
        unsigned long pressDuration = now - pressStart;

        if (pressDuration >= LONG_PRESS_MS) {
            // Long press → deep sleep
            goToDeepSleep();
        } else if (pressDuration >= SHORT_PRESS_MS) {
            // Short press → scan
            if (!scanRunning) {
                lastActivity = now;
                createLoadingUI();
                lv_timer_handler();   // force draw
                delay(200);

                scanRunning = true;
                runScan();          // BLOCKING scan
                scanRunning = false;

                createResultsUI();
                
                // Cancel any existing results timer
                if (results_timer) {
                    lv_timer_del(results_timer);
                    results_timer = nullptr;
                }
                
                // Start 1 minute timer to auto-return to main UI
                results_timer = lv_timer_create(resultsTimeout, 60000, nullptr);
                //lv_timer_handler();
            }
        }
    }

    lastButtonState = buttonState;

    // Auto deep sleep after idle timeout
    if (!scanRunning && (millis() - lastActivity > IDLE_TIMEOUT_MS)) {
    goToDeepSleep();
    }

    delay(10);
}

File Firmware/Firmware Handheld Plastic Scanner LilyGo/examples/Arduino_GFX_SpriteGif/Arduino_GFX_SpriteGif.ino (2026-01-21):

/*******************************************************************************
 * Sprite GIF Demo
 * This is a sprite demo using a static GIF as a master image
 * Image Source:
 * https://www.freepik.com/free-vector/urban-life-drawing_727890.htm#query=city%20road
 * https://giphy.com/gifs/car-carro-nQaMsylXcTIRNorQLJ
 ******************************************************************************/
//  * @note      2.1-inch and 2.8-inch have different initialization sequences, please turn on the correct option below
//  * @note      2.1-inch and 2.8-inch have different initialization sequences, please turn on the correct option below
//  * @note      2.1-inch and 2.8-inch have different initialization sequences, please turn on the correct option below

//! Place the gif file in the data directory into the SD card
#define GIF_FILENAME "/city17_240.gif"


#define GFX_DEV_DEVICE LILYGO_T_RGB
#include <Arduino_GFX_Library.h>
#include <Wire.h>

extern  const uint8_t st7701_type20_init_operations[297];

#define GFX_BL 46
Arduino_DataBus *bus = new Arduino_XL9535SWSPI(8 /* SDA */, 48 /* SCL */, 2 /* XL PWD */, 3 /* XL CS */, 5 /* XL SCK */, 4 /* XL MOSI */);
Arduino_ESP32RGBPanel *rgbpanel = new Arduino_ESP32RGBPanel(
    45 /* DE */, 41 /* VSYNC */, 47 /* HSYNC */, 42 /* PCLK */,
    21 /* R0 */, 18 /* R1 */, 17 /* R2 */, 16 /* R3 */, 15 /* R4 */,
    14 /* G0 */, 13 /* G1 */, 12 /* G2 */, 11 /* G3 */, 10 /* G4 */, 9 /* G5 */,
    7 /* B0 */, 6 /* B1 */, 5 /* B2 */, 3 /* B3 */, 2 /* B4 */,
    1 /* hsync_polarity */, 50 /* hsync_front_porch */, 1 /* hsync_pulse_width */, 30 /* hsync_back_porch */,
    1 /* vsync_polarity */, 20 /* vsync_front_porch */, 1 /* vsync_pulse_width */, 30 /* vsync_back_porch */,
    1 /* pclk_active_neg */);

// ! T-RGB 2.1 inches 
// https://www.lilygo.cc/products/t-rgb?variant=42407295877301
// https://www.lilygo.cc/products/t-rgb
Arduino_RGB_Display     *gfx = new Arduino_RGB_Display(
    480 /* width */, 480 /* height */, rgbpanel, 0 /* rotation */, true /* auto_flush */,
    bus, GFX_NOT_DEFINED /* RST */, st7701_type4_init_operations, sizeof(st7701_type4_init_operations));

// ! T-RGB 2.8 inches Uncomment below
// https://www.lilygo.cc/products/t-rgb?variant=42880799441077
// Arduino_RGB_Display     *gfx = new Arduino_RGB_Display(
//     480 /* width */, 480 /* height */, rgbpanel, 0 /* rotation */, true /* auto_flush */,
//     bus, GFX_NOT_DEFINED /* RST */, st7701_type20_init_operations, sizeof(st7701_type20_init_operations));


Arduino_Canvas_Indexed *canvasGfx = new Arduino_Canvas_Indexed(480 /* width */, 480 /* height */, gfx);
/*******************************************************************************
 * End of Arduino_GFX setting
 ******************************************************************************/
#include <SD_MMC.h>
#include "GifClass.h"

static GifClass gifClass;

uint8_t *spriteMaster;
bool spriteInitiated = false;

#include "IndexedSprite.h"
IndexedSprite *background;
IndexedSprite *road;
IndexedSprite *cars;
IndexedSprite *birds;
IndexedSprite *sun;
IndexedSprite *clouds;
IndexedSprite *mpv;

int frame = 0;
int fpsSnapShot = 0;
unsigned long nextSnap = 0;

void setup()
{
    Serial.begin(115200);
    // Serial.setDebugOutput(true);
    // while(!Serial);
    Serial.println("Arduino_GFX GIF Sprite example");

    Wire.begin(8 /* SDA */, 48 /* SCL */, 400000 /* speed */);

    // Init Display
    if (!canvasGfx->begin()) {
        Serial.println("canvasGfx->begin() failed!");
    }
    canvasGfx->fillScreen(BLACK);
    canvasGfx->flush();
    canvasGfx->setDirectUseColorIndex(true);

    pinMode(GFX_BL, OUTPUT);
    digitalWrite(GFX_BL, HIGH);

    //setup sdcard
    SD_MMC.setPins(39, 40, 38);
    if (!SD_MMC.begin("/sdcard", true)) {
        Serial.println(F("ERROR: File System Mount Failed!"));
        gfx->println(F("ERROR: File System Mount Failed!"));
        exit(0);
    }

    uint8_t cardType = SD_MMC.cardType();
    if (cardType != CARD_NONE) {
        Serial.print("SD Card Type: ");
        if (cardType == CARD_MMC)
            Serial.println("MMC");
        else if (cardType == CARD_SD)
            Serial.println("SDSC");
        else if (cardType == CARD_SDHC)
            Serial.println("SDHC");
        else
            Serial.println("UNKNOWN");
        uint64_t cardSize = SD_MMC.cardSize() / (1024 * 1024);
        Serial.printf("SD Card Size: %lluMB\n", cardSize);
    }


    File gifFile = SD_MMC.open(GIF_FILENAME, FILE_READ);
    if (!gifFile || gifFile.isDirectory()) {
        Serial.println(F("ERROR: open gifFile Failed!"));
        gfx->println(F("ERROR: open gifFile Failed!"));
    } else {
        // read GIF file header
        gd_GIF *gif = gifClass.gd_open_gif(&gifFile);
        if (!gif) {
            Serial.println(F("gd_open_gif() failed!"));
        } else {
            spriteMaster = (uint8_t *)malloc(gif->width * gif->height / 2);
            if (!spriteMaster) {
                Serial.println(F("spriteMaster malloc failed!"));
            } else {
                int32_t res = gifClass.gd_get_frame(gif, spriteMaster);

                if (res > 0) {
                    // inital palette
                    uint16_t *palette = canvasGfx->getColorIndex();
                    memcpy(palette, gif->palette->colors, gif->palette->len * 2);

                    //IndexedSprite(x, y, *bitmap, *palette, w, h, x_skip, loop, frames, speed_divider, chroma_key)
                    background = new IndexedSprite(0, 0, spriteMaster, palette, 405, 180, 0, true, 1, 3);
                    road = new IndexedSprite(0, 180, spriteMaster + (180 * 405), palette, 405, 60, 0, true, 1, 1);
                    cars = new IndexedSprite(0, 182, spriteMaster + (240 * 405), palette, 405, 11, 0, true, 1, 1, gif->gce.tindex);
                    birds = new IndexedSprite(0, 80, spriteMaster + (251 * 405), palette, 51, 32, (405 - 51), false, 4, 4, gif->gce.tindex);
                    sun = new IndexedSprite(16, 16, spriteMaster + (251 * 405) + 210, palette, 30, 30, (405 - 30), false, 1, 0, gif->gce.tindex);
                    clouds = new IndexedSprite(0, 2, spriteMaster + (283 * 405), palette, 405, 94, 0, true, 1, 2, gif->gce.tindex);
                    mpv = new IndexedSprite((canvasGfx->width() - 70) / 2, 182, spriteMaster + (377 * 405), palette, 50, 30, (405 - 50), false, 8, 2, gif->gce.tindex);

                    spriteInitiated = true;
                }

                gifClass.gd_close_gif(gif);
            }
        }
    }

    canvasGfx->setTextColor(0xfd, 0x00);
    canvasGfx->setTextSize(1);
}
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

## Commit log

2026-01-18 hardware cleaned folders initial upload
    [ADS1256IDBT 2.stp, ADS1256IDBT.stp, AP7312-1833W6-7.stp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]
2026-01-21 Firmware add
    [BOM_PCB.csv, ScreenSize.dwg, T-RGB-FULL-3D-2.1-Inches.stp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]
2026-01-21 structure update
    [ADS1256IDBT 2.stp, ADS1256IDBT.stp, AP7312-1833W6-7.stp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]
2026-01-22 BOM as xlsx
    [BOM_PCB.xlsx]
2026-01-22 step files add
    [fixture_LCD.STEP, low_shell_angle.STEP, top_shell_angle.STEP]
